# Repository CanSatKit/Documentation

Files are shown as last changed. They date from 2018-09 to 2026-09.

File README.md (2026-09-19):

# CanSat Kit — Documentation

Documentation, user manuals and hardware design files for the **CanSat Kit** —
a starter kit for building a CanSat minisatellite and its ground station,
compatible with the requirements of the *CanSats in Europe* competition and the
Polish CanSat competition organised by ESERO-PL.

This repository holds the released documentation for both generations of the kit.

## Repository contents

| Path | Description |
| --- | --- |
| [`CanSatKit v2/`](CanSatKit%20v2) | Documentation for CanSat Kit rev. 2 (current) |
| [`CanSatKit v1/`](CanSatKit%20v1) | Documentation for CanSat Kit rev. 1.x (legacy) |

Each version folder contains:

- **User manual** — kit contents, technical parameters, connector and
  LED maps, power supply, sensors, radio link, Arduino IDE setup, safety and
  correct-use rules.
- **PCB main** — schematic and PCB drawings (PDF) plus 3D models (STEP, full and
  simplified) of the main CanSat / ground-station board.
- **PCB proto** — schematic, PCB drawings and 3D models of the
  prototyping board.

## Using the 3D models

The `.step` files are provided for mechanical integration of the boards into a
CanSat structure. Where both a full and a simplified model exist, prefer the
simplified one for assembly and envelope checks — it is significantly lighter to
load in CAD software.

## Safety

Before using the kit, read the user manual for your kit revision, in particular
the chapter on safety and correct use. Pay attention to the battery handling and radio transmission
rules described there.

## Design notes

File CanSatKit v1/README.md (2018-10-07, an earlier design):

# Documentation
Documentation, manuals and help for CanSat Kit

# Schematics and Board design files

Available from CircuitMaker:
 - Kit: https://circuitmaker.com/Projects/Details/Michal-Gumiela/CansatKit-ATSAM
 - Protoboard: https://circuitmaker.com/Projects/Details/Michal-Gumiela/CansatKit-Protoboard

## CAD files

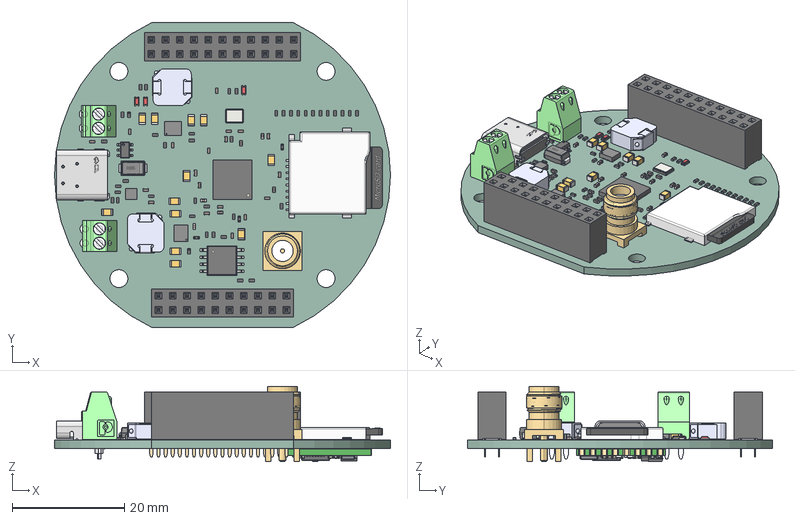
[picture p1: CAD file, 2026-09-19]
CanSatKit v2/PCB main/CansatKit v2.0 - simplified.step
60.0 x 54.4 x 13.5 mm
C_0402_1005Metric x 25
R_0402_1005Metric x 44
CAPC0805 v2 x 12
PinSocket_2x11_P2.54mm_Vertical
SPM6530T-100M x 2
mpt_0.5-2-2.54 x 2
QFN-56-1EP_7x7mm_Pitch0.4mm
SOIC-8_5.3x5.3mm_P1.27mm
User Library-SMA_Stehend_Amp 132134RP-1_1
User Library-SMA_Stehend_Amp 132134RP-1_2
User Library-micro-sd-card
Crystal_SMD_3225-4Pin_3.2x2.5mm
User Library-SOT23-6-2
RNR11 x 2
User Library-led_0603 x 3
VQFN-10_L2.0-W2.0-P0.45-TL
PinSocket_2x10_P2.54mm_Vertical
User Library-RFM96W_Board
User Library-RFM96W_Cap0402 x 21
User Library-RFM96W_SW3dPS-inductor_0402_white x 5
User Library-RFM96W_SW3dPS-SOT-23-6
User Library-RFM96W_QFN28
User Library-RFM96W_TXC_7M
User Library-RFM96W_Res0402 x 4
User Library-RFM96W_User_Library-3-lead_sot23-3
User Library-RFM96W_Goldcontact x 16
CansatKit - RPi-unsaved-export-nT6Vkn_PCB

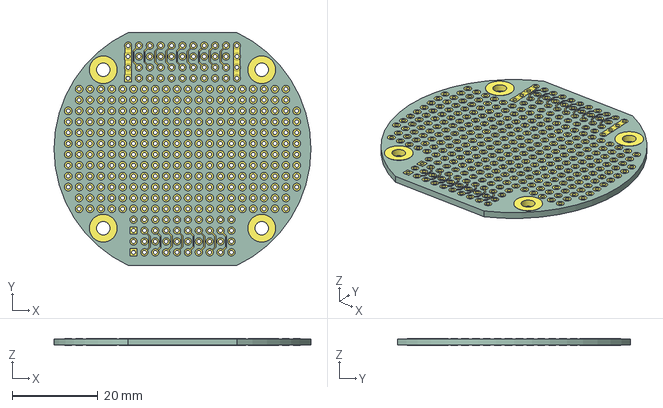
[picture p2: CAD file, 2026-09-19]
CanSatKit v2/PCB proto/CansatKit v2.0 - protoboard.step
60.0 x 54.4 x 1.59 mm
CansatKit - protoboard-unsaved-export-QVb27Q_copper
CansatKit - protoboard-unsaved-export-QVb27Q_PCB

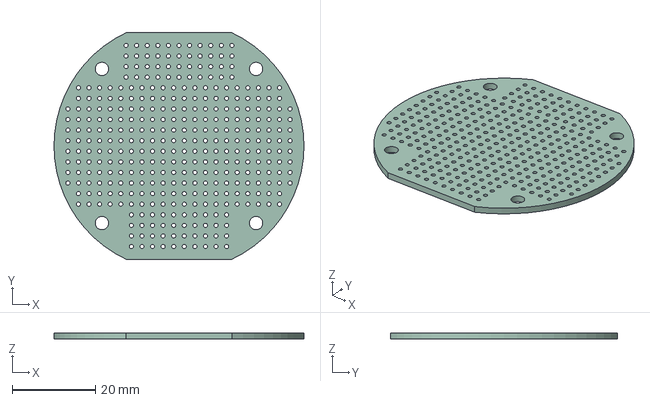
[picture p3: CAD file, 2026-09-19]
CanSatKit v2/PCB proto/CansatKit v2.0 - protoboard simplified.step
60.0 x 54.4 x 1.51 mm

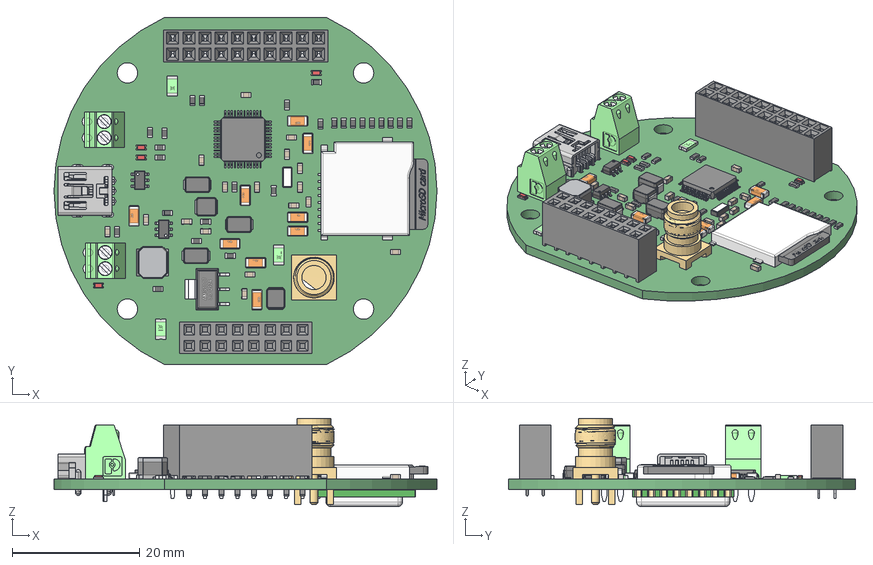
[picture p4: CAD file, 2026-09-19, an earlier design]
CanSatKit v1/PCB Main/main-full.step
60.0 x 54.4 x 13.8 mm
Board
User_Library-micro-sd-card
User_Library-RFM96W_Board
User_Library-RFM96W_Goldcontact x 16
User_Library-res0603-1 x 26
SSW-108-01-X-D_RGB5263440
User_Library-SMD_CAPACITOR x 17
User_Library-nona_SMD075F x 3
User_Library-SMA_Stehend_Amp_132134RP-1_1
User_Library-SMA_Stehend_Amp_132134RP-1_2
User_Library-led_0603LED0603_red x 4
mpt_0.5-2-2 x 2
AMS1117
M20-78310_MOULD
M20-782_CONTACT x 20
SW3dPS-1206_SMD_Capacitor x 9
DO-214AC x 3
User_Library-TQFP-48_pins_TQFP_pin_TQFP_022x07_1 x 48
User_Library-TQFP-48_body_10x1_TQFP_7x7_1
SRN5040series
User_Library-SOT23-6-2 x 2
FX135
AVX-B x 2

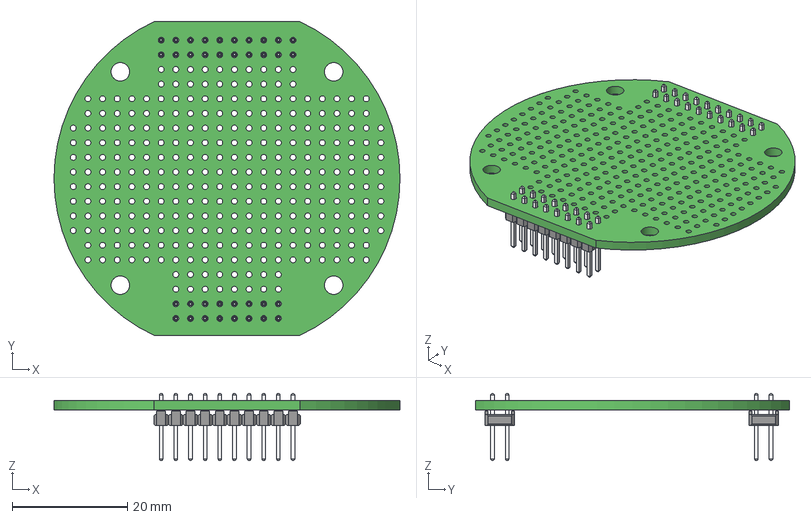
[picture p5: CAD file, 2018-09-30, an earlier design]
CanSatKit v1/PCB Proto/proto.step
60.0 x 54.4 x 11.7 mm
Board
M20-998-MOULD x 2
M20-998-PIN x 36

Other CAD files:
CanSatKit v1/PCB Main/main-simple.step

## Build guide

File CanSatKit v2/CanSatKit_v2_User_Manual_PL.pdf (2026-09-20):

# Dokumentacja zestawu startowego CanSat Kit v2

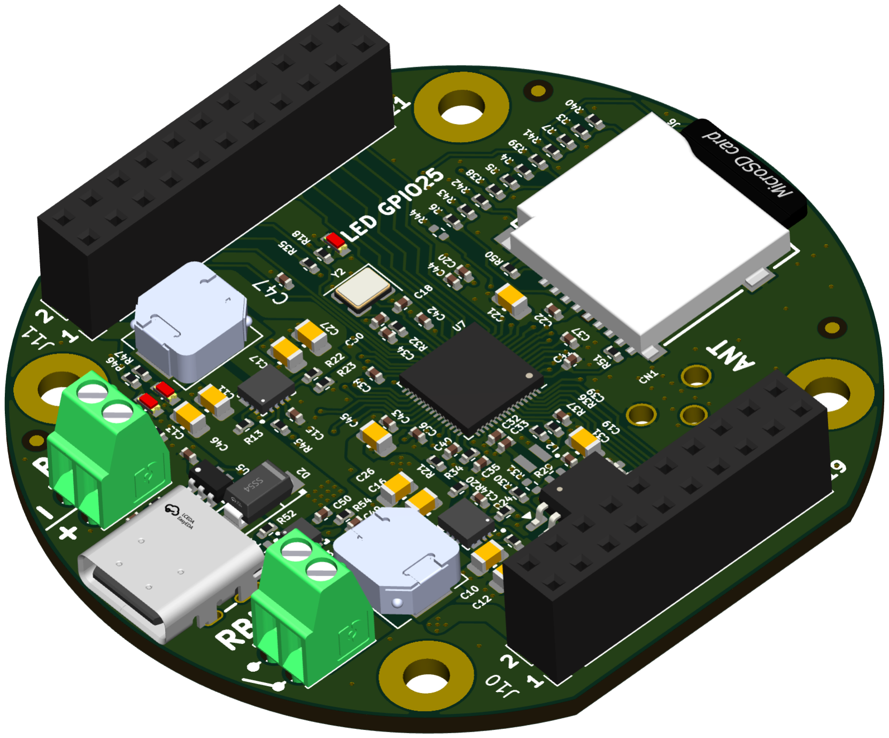
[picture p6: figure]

Rewizja dokumentu: v1.0 (2026-09) Dotyczy zestawu CanSat Kit rev. 2

# 1 Spis treści

## 2 Przeznaczenie zestawu

Zestaw startowy CanSat Kitzaprojektowany został jako platforma do budowy minisatelity CanSat oraz stacji naziemnej zgodnych z wymaganiami konkursu „CanSats in Europe” oraz polskich zawodów CanSat organizowanych przez ESERO-PL.
!"# Przed użyciem zestawu należy zapoznać się z niniejszym dokumentem,

w szczególności z rozdziałem 7. Bezpieczeństwo i zasady prawidłowego użytkowania.

## 3 Elementy zestawu

Zestaw zawiera niezbędne komponenty elektroniczne do wypełnienia misji podstawowej minisatelity CanSat: moduł zasilania (bez akumulatora/baterii), komputer pokładowy, moduły łączności bezprzewodowej, a także czujniki temperatury i ciśnienia atmosferycznego.
Obudowa minisatelity CanSat, system odzysku (np. spadochron) oraz akumulator/bateria zasilająca powinny zostać wykonane/dodane przez użytkownika zestawu według wymagań danego minisatelity.

Zestaw CanSat Kit składa się z następujących elementów:
- 2 x płytka główna CanSata / stacji naziemnej
- 1 x płytka drukowana prototypowa
- 1 x czujnik temperatury - termistor NTC 10k
- 1 x rezystor 10k
- 1 x czujnik ciśnienia BMP280
- 2 x kabel USB-C
- 1 x złącze antenowe SMA
- 1 x listwa kołkowa 2x40-pin 2.54 mm
- 2 x złącze śrubowe typu terminal block 2.54 mm
- 1 x płytka stykowa

- 8 x kabel do płytki stykowej
- 1 x opakowanie ESD

## 4 Parametry techniczne

## 4.1 Płytka główna CanSata / stacji naziemnej

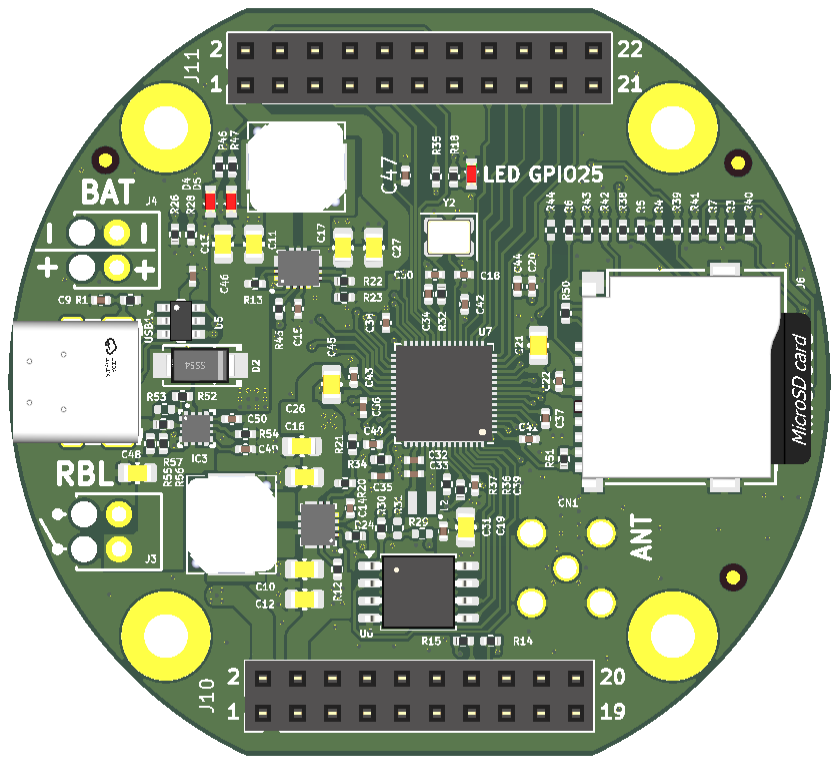
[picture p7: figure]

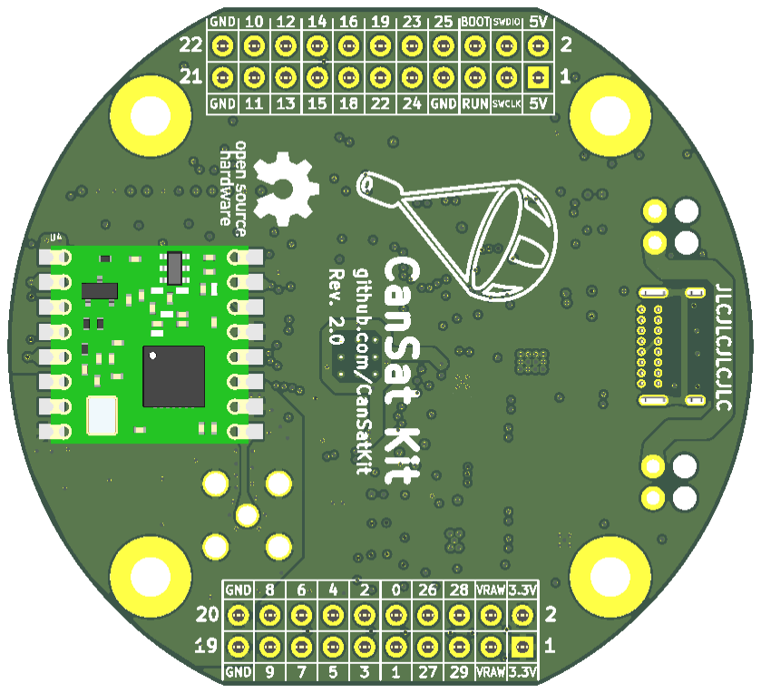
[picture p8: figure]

## 4.1.1 Informacje ogólne

Płytka główna dedykowana jest do użycia zarówno w minisatelicie CanSat, jak i w stacji naziemnej do odbioru danych drogą radiową.
Płytka główna składa się z następujących bloków:
- układ zasilania - umożliwia zasilenie płytki i urządzeń zewnętrznych z ogniw baterii litowo-jonowej (1S, 2S lub 3S), innych ogniw o napięciach w zakresie 3 - 13 V lub złącza USB;
- komputer pokładowy - mikrokontroler zgodny z Arduino / Raspberry Pi Pico 2 (RP2350), z możliwością programowania przez port USB;
- magazyn danych -złącze na kartę microSD, dostępne z poziomu komputera pokładowego;
- moduł łączności bezprzewodowej - układ radiowy nadawczo-odbiorczy, oparty o standard LoRa, z zewnętrznym złączem antenowym.

## 4.1.2 Mapa złącz, gniazd i diod LED

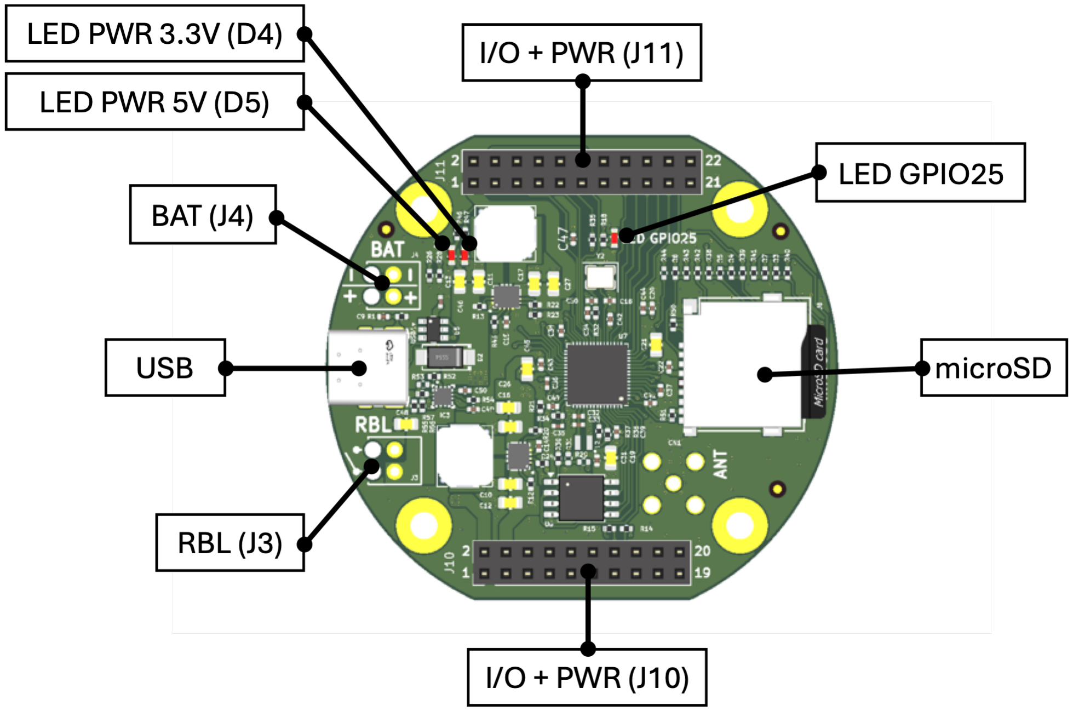
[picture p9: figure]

Tabela 1. Złącza płytki głównej / stacji naziemnej

Nazwa złącza | Opis i funkcje
BAT (J4) | • złącze zasilania zewnętrznego (np. z baterii): 3 - 13 V • raster 2.54 mm • możliwość wlutowania złącza typu listwa kołkowa (header), śrubowego (terminal block) lub przylutowania przewodów (ze stress reliefem) (https://cdn.sparkfun.com/assets/5/3/b/f/2/526d7970757b7f7f708b4568.jpg)
RBL (J3) | • zworka zasilania - raster 2.54 mm • możliwość wpięcia głównego włącznika
USB-C (USB1) | • zasilanie • programowanie mikrokontrolera z Arduino IDE • przesyłanie danych (Serial port) • po więcej szczegółów zobacz dokumentację Arduino/ Raspberry Pi Pico 2 dotyczącą złącza USB
J10, J11 | • złącze kołkowe żeńskie 2.54 mm • dostępne napięcia zasilające • wyprowadzone wejścia/wyjścia mikrokontrolera
micro SD | • złącze na karty pamięci micro SD • podłączone do mikrokontrolera - zob. 4.1.5
ANT | • złącze anteny modułu radiowego • możliwość przylutowania złącza SMA (https://media.rs-online.com/t_large/F6163422-01.jpg) np. do wkręcenia większej anteny (w stacji naziemnej) • możliwość przylutowania anteny ćwierćfalowej wykonanej z przewodu

4.1.2.1 Złącze J11

!"# Standard napięć dla pinów mikrokontrolera to 3.3 V. Podłączenie urządzeń pracujących w innych standardach napięciowych (np. 5 V) może skutkować uszkodzeniem zestawu.

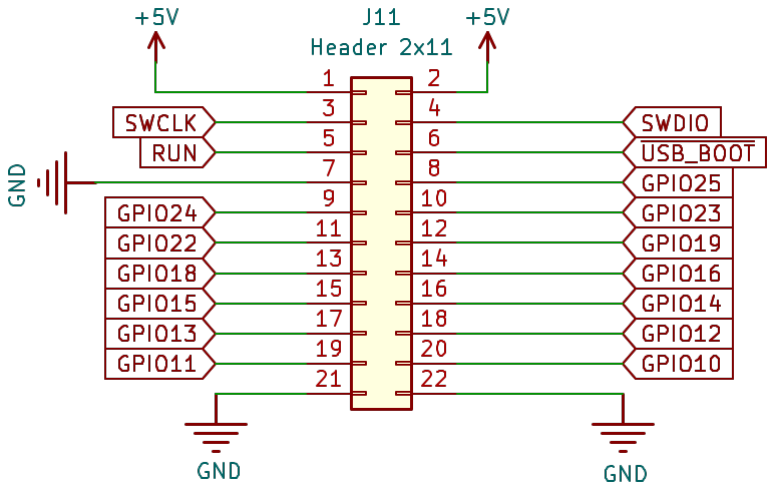
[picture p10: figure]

Tabela 2. Mapa pinów złącza J11

Pin nr | Nazwa na schemacie | Linia RP2350 | Opis | Funkcje alternatywne (RP2350)
1 | 5V | - | Zasilanie +5 V (wyjście przetwornicy IC2) | -
2 | 5V | - | Zasilanie +5 V (wyjście przetwornicy IC2) | -
3 | SWCLK | SWCLK | Zegar interfejsu SWD - programowanie i debugowanie zewnętrznym programatorem | -
4 | SWDIO | SWDIO | Linia danych interfejsu SWD | -
5 | RUN | RUN | Reset mikrokontrolera - zwarcie do GND powoduje reset (linia aktywna w stanie niskim) | -
6 | BOOT | QSPI_SS | Wymuszenie trybu bootloadera USB - zwarcie do GND w chwili włączenia zasilania lub resetu (przez rezystor 1 kΩ) | -
7 | GND | - | Masa | -
8 | 25 | GPIO25 | Wejście/wyjście cyfrowe (GPIO), podłączona zielona dioda LED (D1) - odpowiednik LED_BUILTIN | SPI1 CSn, I2C0 SCL, UART1 RX, PWM
9 | 24 | GPIO24 | Wejście/wyjście cyfrowe (GPIO) | SPI1 RX, I2C0 SDA, UART1 TX, PWM
10 | 23 | GPIO23 | Wejście/wyjście cyfrowe (GPIO) | SPI0 TX, I2C1 SCL, PWM
11 | 22 | GPIO22 | Wejście/wyjście cyfrowe (GPIO). Opcjonalnie sygnał DIO1 modułu radiowego - zob. przypis 1 | SPI0 SCK, I2C1 SDA, PWM
12 | 19 | GPIO19 | Interfejs SPI0 - linia MOSI (TX). Podłączony czytnik kart microSD oraz moduł radiowy | SPI0 TX, I2C1 SCL, PWM
13 | 18 | GPIO18 | Interfejs SPI0 - linia SCK. Podłączony czytnik kart microSD oraz moduł radiowy | SPI0 SCK, I2C1 SDA, PWM
14 | 16 | GPIO16 | Interfejs SPI0 - linia MISO (RX). Podłączony czytnik kart microSD oraz moduł radiowy | SPI0 RX, I2C0 SDA, UART0 TX, PWM
15 | 15 | GPIO15 | Wejście/wyjście cyfrowe (GPIO) | SPI1 TX, I2C1 SCL, UART0 RX, PWM
16 | 14 | GPIO14 | Wejście/wyjście cyfrowe (GPIO) | SPI1 SCK, I2C1 SDA, UART0 TX, PWM
17 | 13 | GPIO13 | Wejście/wyjście cyfrowe (GPIO) | SPI1 CSn, I2C0 SCL, UART0 RX, PWM
18 | 12 | GPIO12 | Wejście/wyjście cyfrowe (GPIO) | SPI1 RX, I2C0 SDA, UART0 TX, PWM
19 | 11 | GPIO11 | Wejście/wyjście cyfrowe (GPIO) | SPI1 TX, I2C1 SCL, PWM
20 | 10 | GPIO10 | Wejście/wyjście cyfrowe (GPIO) | SPI1 SCK, I2C1 SDA, PWM
21 | GND | - | Masa | -

22 | GND | - | Masa | -

4.1.2.2 Złącze J10

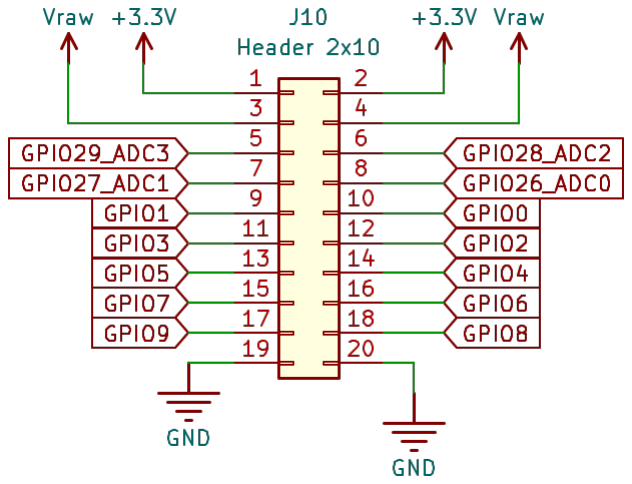
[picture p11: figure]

Tabela 3. Mapa pinów złącza J10

Pin nr | Nazwa na schemacie | Linia RP2350 | Opis | Funkcje alternatywne (RP2350)
1 | 3.3V | - | Zasilanie +3.3 V (wyjście przetwornicy IC1) | -
2 | 3.3V | - | Zasilanie +3.3 V (wyjście przetwornicy IC1) | -
3 | VRAW | - | Napięcie wejściowe za zabezpieczeniem (eFuse) | -
4 | VRAW | - | Napięcie wejściowe za zabezpieczeniem (eFuse) | -
5 | 29 | GPIO29 | Wejście/wyjście cyfrowe (GPIO), wejście analogowe ADC3 | ADC3, SPI1 CSn, UART0 RX, I2C0 SCL, PWM
6 | 28 | GPIO28 | Wejście/wyjście cyfrowe (GPIO), wejście analogowe ADC2 | ADC2, SPI1 RX, UART0 TX, I2C0 SDA, PWM
7 | 27 | GPIO27 | Wejście/wyjście cyfrowe (GPIO), wejście analogowe ADC1 | ADC1, SPI1 TX, I2C1 SCL, PWM
8 | 26 | GPIO26 | Wejście/wyjście cyfrowe (GPIO), wejście analogowe ADC0 | ADC0, SPI1 SCK, I2C1 SDA, PWM
9 | 1 | GPIO1 | Wejście/wyjście cyfrowe (GPIO), domyślnie UART0 RX (w Arduino IDE Serial1) | UART0 RX, SPI0 CSn, I2C0 SCL, PWM
10 | 0 | GPIO0 | Wejście/wyjście cyfrowe (GPIO), domyślnie UART0 TX (w Arduino IDE Serial1) | UART0 TX, SPI0 RX, I2C0 SDA, PWM
11 | 3 | GPIO3 | Wejście/wyjście cyfrowe (GPIO) | SPI0 TX, I2C1 SCL, UART0 RX, PWM
12 | 2 | GPIO2 | Wejście/wyjście cyfrowe (GPIO) | SPI0 SCK, I2C1 SDA, UART0 TX, PWM
13 | 5 | GPIO5 | Interfejs I2C - linia SCL (clock). Na płytce rezystor podciągający 4.7 kΩ do 3.3 V | I2C0 SCL, SPI0 CSn, UART1 RX, PWM
14 | 4 | GPIO4 | Interfejs I2C - linia SDA (data). Na płytce rezystor podciągający 4.7 kΩ do 3.3 V | I2C0 SDA, SPI0 RX, UART1 TX, PWM
15 | 7 | GPIO7 | Wejście/wyjście cyfrowe (GPIO) | I2C1 SCL, SPI0 TX, PWM
16 | 6 | GPIO6 | Wejście/wyjście cyfrowe (GPIO) | I2C1 SDA, SPI0 SCK, PWM
17 | 9 | GPIO9 | Wejście/wyjście cyfrowe (GPIO) | SPI1 CSn, I2C0 SCL, UART1 RX, PWM
18 | 8 | GPIO8 | Wejście/wyjście cyfrowe (GPIO) | SPI1 RX, I2C0 SDA, UART1 TX, PWM
19 | GND | - | Masa | -
20 | GND | - | Masa | -

4.1.2.3 Diody

Tabela 4. Diody świecące (LED) dostępne na płytce i ich funkcje

Nazwa diody | Opis
LED GPIO25 | Dioda LED podłączona do pinu GPIO25 mikrokontrolera - użyj np. przykładu „Blink” z Arduino, kompatybilna z diodą w Raspberry Pi Pico 2 i Arduino (LED_BUILTIN)
LED PWR D4 | Dioda sygnalizująca obecność napięcia na linii zasilania 3.3 V
LED PWR D5 | Dioda sygnalizująca obecność napięcia na linii zasilania 5 V

## 4.1.3Układ zasilania

Układ zasilania obecny na płytce odpowiada za konwersję energii elektrycznej, dystrybucję na płytce głównej do zasilania jej podzespołów oraz dostarczenie energii do zasilenia układów dołączanych do płytki głównej przez użytkownika.

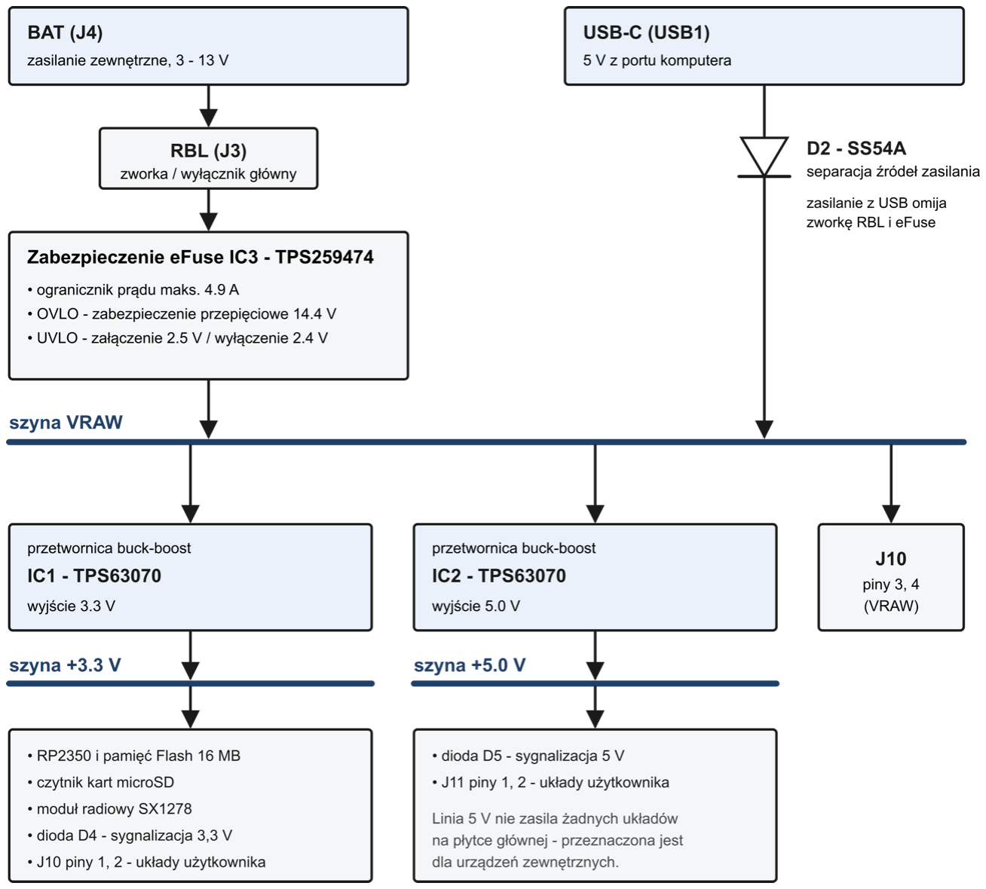
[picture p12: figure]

Płytka główna może być zasilana na kilka różnych sposobów, które zostały przedstawione poniżej:

1) Złącze zasilające J4 (BAT)
̶ minimalne napięcie wejściowe: 3.0 V
̶ maksymalne napięcie wejściowe: 13.0 V
̶ zasilenie układów płytki ze złącza BAT następuje tylko wtedy, gdy zwarta jest zworka oznaczona jako RBL,
̶ zalecane jest zasilanie płytki z akumulatorów litowo-jonowych od 1 do 3 celi szeregowo (1S
- 3S)
̶ Przy zasilaniu ze złącza BAT (J4) napięcie Vraw będzie odpowiadało dostarczonemu napięciu na tym złączu

2) Złącze USB-C (USB1)
̶ maksymalne napięcie wejściowe: 5.5 V
̶ podłączenie płytki za pomocą złącza USB-C spowoduje zasilenie jej modułów (w tym pojawienie się napięcia na liniach zasilających 5 V i 3.3 V na złączu J10 i J11) niezależnie od stanu zworki RBL.
̶ Przy podłączeniu złącza USB napięcie Vraw będzie wynosiło ok. 4.5-5 V (podłączenie przez diodę Schottkiego)

!"# Zamiana polaryzacji zasilania może powodować nieodwracalne uszkodzenia na płytce!

!"# Podłączenie napięcia większego niż maksymalne napięcie podane w specyfikacji dla danego wejścia może spowodować nieodwracalne uszkodzenia na płytce!

Układ dostarcza następujące linie zasilania na złączach J10 i J11:
- linia 5 V
- napięcie nominalne: 5.0 V
- wydajność prądowa:
- 1 A - dla napięcia wejściowego min. 3 V (1S/1xli-ion)
- 1.5 A - dla napięcia wejściowego min. 6 V (2S/2xli-ion)
- linia 3.3 V
- napięcie nominalne: 3.3 V
- wydajność prądowa:
- 1 A - dla napięcia wejściowego min. 3 V (1S/1xli-ion)
- 1.5 A - dla napięcia wejściowego min. 6 V (2S/2xli-ion)
- linia Vraw
- bezpośrednie napięcie z baterii (za zworką RBL) lub złącza USB-C (przez diodę Schottkiego)
- wydajność prądowa: zabezpieczenie na maksymalnie 4.9 A

!"# W przypadku poboru większego prądu niż podano w specyfikacji dla danej linii, zostanie aktywowane zabezpieczenie nadprądowe, które skutkuje odłączeniem linii na pewien okres czasu. Cała płytka powinna zostać odłączona od zasilania na kilka minut, aby przywrócić napięcie na odłączonej linii.

Zworka RBL:
Zworka RBL jest podłączona szeregowo z pinem „+” złącza BAT (J4). Zalecane jest podłączenie przełącznika do złącza RBL (J3), który będzie pełnił funkcję głównego włącznika CanSata. Jeśli przełącznik jest zlokalizowany w innym miejscu, złącze RBL (J3) można zewrzeć.

!"# Zworka ma wpływ tylko i wyłącznie na odłączanie/włączanie źródła zasilania podpiętego do złącza BAT (J4). Nie ma ona wpływu, jeśli płytka zasilana jest przez złącze USB-C (USB1).

## 4.1.4 Mikrokontroler

Raspberry Pi RP2350A to wydajny, dwurdzeniowy mikrokontroler o architekturze hybrydowej: zawiera dwa rdzenie ARM Cortex-M33 oraz dwa rdzenie Hazard3 (RISC-V), z których użytkownik wybiera parę uruchamianą po starcie. Płytka jest programowo zgodna z modułem Raspberry Pi Pico 2.
Programowanie mikrokontrolera odbywa się przez port USB-C bezpośrednio z Arduino IDE (środowisko samo przełącza płytkę w tryb bootloadera).
Parametry techniczne
Mikrokontroler | RP2350A, QFN-60 7 x 7 mm
Architektura rdzeni | 2 x ARM Cortex-M33 (z FPU i DSP) lub 2 x Hazard3 (RISC-V RV32IMAC)
Napięcie pracy wejść/wyjść | 3.3 V
Pamięć Flash | 16 MB (zewnętrzna, W25Q128JVS, magistrala QSPI)
Pamięć SRAM | 520 KB
Częstotliwość zegara | 150 MHz
Rezonator | kwarc 12 MHz (Y2)

Przetwornik ADC | 12-bitowy, 4 kanały (GPIO26 - GPIO29)
USB | natywny kontroler USB 1.1 (Full Speed, 12 Mb/s), tryb device

Dostępne dla użytkownika interfejsy zostały wymienione w tabelach 4.1.2.1 oraz 4.1.2.2.

!"# Wydajność prądowa pojedynczego pinu mikrokontrolera jest konfigurowalna (2, 4, 8 lub 12 mA). Wartość domyślna to 4 mA. Zaleca się nieprzekraczanie 8 mA na pin.

## 4.1.5 Czytnik kart microSD

Czytnik kart microSD został podłączony do mikrokontrolera poprzez interfejs SPI, zgodnie z poniższą tabelą.
Pin karty SD (funkcja w trybie SPI karty SD) | Pin mikrokontrolera
DAT0 (MISO) | GPIO16
CMD (MOSI) | GPIO19
CLK (Clock / SCK) | GPIO18
DAT3 (Chip Select / CS) | GPIO21

🛈 Więcej informacji o podłączaniu karty SD do Arduino można znaleźć

w dokumentacji biblioteki (https://www.arduino.cc/en/Reference/SD) oraz poradniku. (https://www.arduino.cc/en/Reference/SDCardNotes)

## 4.1.6 Moduł radiowy

Moduł radiowy SX1278 został podłączony do mikrokontrolera poprzez interfejs SPI oraz dodatkowe piny GPIO, zgodnie z poniższą tabelą:

Pin modułu SX1278 | Pin mikrokontrolera
MISO | GPIO16
MOSI | GPIO19

SCK | GPIO18
NSS (Chip Select) | GPIO17
DIO0 | GPIO20
DIO1 | GPIO22 (przypis 1)
RESET | niepodłączony

Przypisy:

1
- domyślnie pin DIO1 nie jest podłączony do pinu GPIO22 mikrokontrolera; aby to zrobić, należy wlutować rezystor R44 - rozmiar SMD 0402 o wartości ok. 100 Ω lub zworkę, np. kawałek drutu. Nie jest to jednak konieczne do wykonania misji CanSata.

🛈 Szczegółowe informacje o module radiowym SX1278 można znaleźć w jego

dokumentacji. (https://cdn-shop.adafruit.com/product-files/3179/sx1276_77_78_79.pdf)

## 4.1.7 Parametry mechaniczne

Kształt płytki: koło o promieniu 30 mm ze ściętymi fragmentami - w miejscu ścięcia szerokość 54.4 mm.
Na płytce rozmieszczone są 4 otwory montażowe przeznaczone na śruby M3 (średnica 3.2 mm). Otwory posiadają metalizowane obręcze (średnica 6.5 mm), podłączone bezpośrednio do masy (GND). Dostępne są modele 3D w formacie STEP.

## 4.2 Czujnik temperatury

Termistor NTC (ang. Negative Temperature Coefficient) to rezystor, którego rezystancja maleje wraz ze wzrostem temperatury. W odróżnieniu od czujników aktywnych termistor nie wytwarza napięcia proporcjonalnego do temperatury - jest elementem czysto biernym, dlatego do pomiaru konieczny jest dzielnik napięcia i przetwornik analogowo-cyfrowy mikrokontrolera.

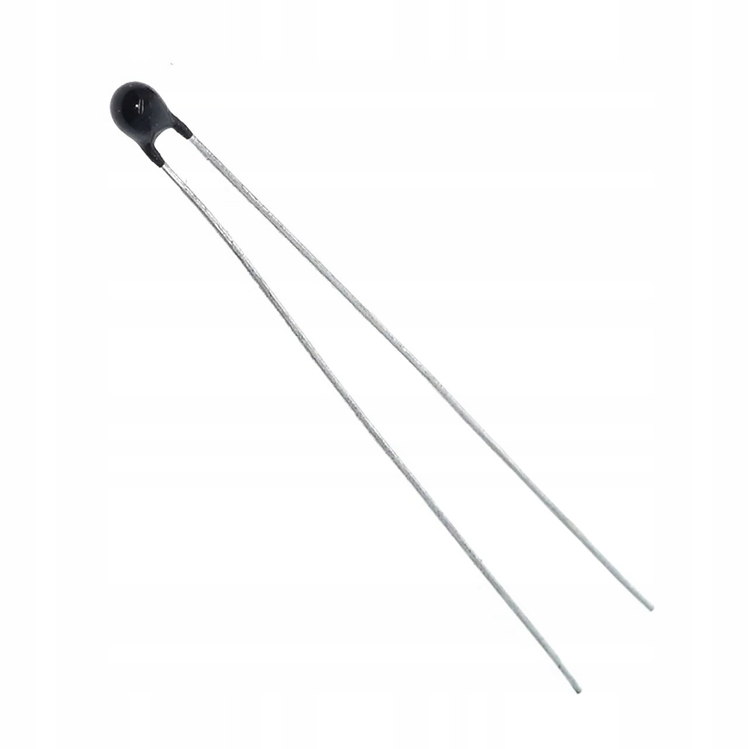
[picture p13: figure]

Zależność rezystancji od temperatury opisuje w przybliżeniu równanie Beta:

1/T = 1/T25 + (1/B) * ln(R / R25)

gdzie T i T25 wyrażone są w kelwinach (T25 = 298.15 K, czyli 25 °C), R25 to rezystancja termistora w temperaturze 25 °C, a B to współczynnik materiałowy podawany w dokumentacji czujnika.
- rezystancja nominalna R25: 10 kΩ
- współczynnik B (B25/85): typowe wartości dla termistorów 10 kΩ mieszczą się w zakresie 3435
- 3988
Termistor pracuje w dzielniku napięcia zasilanym z linii 3.3 V płytki głównej. Rezystor odniesienia R1 o wartości 10 kΩ łączy linię 3.3 V z węzłem pomiarowym (V_ADC), natomiast termistor łączy węzeł pomiarowy (V_ADC) z masą. Węzeł pomiarowy podłączony jest do wejścia przetwornika analogowo-cyfrowego mikrokontrolera (np. pin GPIO27). Polecane jest również dodanie kondensatora (oznaczenie C1) w celu poprawy jakości pomiarów.

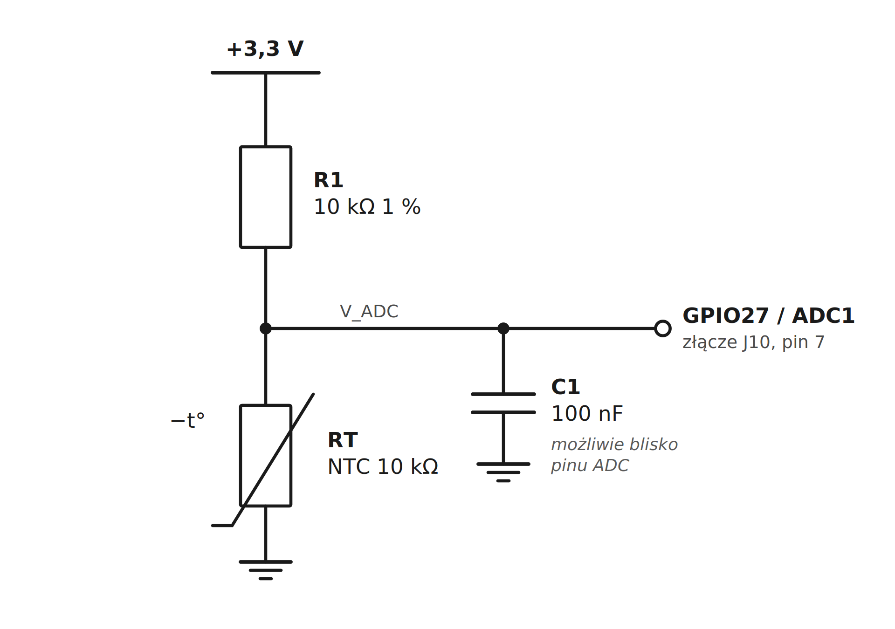
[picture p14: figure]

Charakterystyka dzielnika pomiarowego z termistorem NTC 10 kΩ:

Temperatura | Rezystancja NTC | Napięcie na ADC | Wynik ADC | Rozdzielczość
−40 °C | 401.9 kΩ | 3.220 V | 3996 | 7 LSB/°C
−20 °C | 105.4 kΩ | 3.014 V | 3740 | 20 LSB/°C
−10 °C | 58.3 kΩ | 2.816 V | 3495 | 29 LSB/°C
0 °C | 33.6 kΩ | 2.543 V | 3156 | 38 LSB/°C
+10 °C | 20.2 kΩ | 2.206 V | 2738 | 45 LSB/°C
+25 °C | 10.0 kΩ | 1.650 V | 2048 | 46 LSB/°C
+40 °C | 5.30 kΩ | 1.143 V | 1419 | 37 LSB/°C
+50 °C | 3.59 kΩ | 0.871 V | 1081 | 30 LSB/°C
+60 °C | 2.49 kΩ | 0.657 V | 815 | 23 LSB/°C
+85 °C | 1.09 kΩ | 0.323 V | 401 | 11 LSB/°C

Uwaga - pinu wejścia analogowego, do którego podłączony jest dzielnik, nie wolno konfigurować jako wejścia cyfrowego (wywołanie pinMode(pin_analogowy, INPUT) w programie). GPIO z włączonym buforem wejściowym, którego napięcie znajduje się pomiędzy poziomami logicznymi
- a tak jest zawsze w dzielniku pomiarowym - może pobierać prąd do 120 µA, co całkowicie zaburza pomiar. Funkcja analogRead() wyłącza bufor wejściowy samodzielnie, ale robi to tylko przy pierwszym użyciu danego pinu; późniejsze wywołanie pinMode() na tym samym pinie ponownie włączy bufor i nie zostanie cofnięte.

## 4.3 Czujnik ciśnienia atmosferycznego

🛈 Szczegółowe informacje o czujniku ciśnienia atmosferycznego BMP280 można

znaleźć w jego dokumentacji. (http://www.ti.com/lit/ds/symlink/lm35.pdf)

## 4.3.1 Parametry pomiarowe

- Zakres pomiaru ciśnienia: 300 - 1100 hPa
- Zakres pomiaru temperatury: -40 - 85 °C
- Dokładność bezwzględna (0 - 65 °C): ±1 hPa
- Dokładność względna (700 - 900 hPa przy +25 °C do +40 °C): ±0.12 hPa (odpowiada ±1 m)
- Czas pomiaru: od 5.5 ms

## 4.3.2 Zasilanie

- zakres napięcia zasilania: 1.71 V - 3.6 V
- pobór prądu: < 1 mA

## 4.3.3 Interfejs

- komunikacja z mikrokontrolerem poprzez cyfrowy interfejs I2C (linie SDA i SCL)
- adres I2C czujnika: 0x76
- zarówno płytka główna CanSat Kit, jak i czujnik na swojej płytce posiadają odpowiednie rezystory podciągające linie SDA i SCL (pull-up), wymagane do prawidłowej pracy interfejsu I2C
- alternatywnie możliwość użycia interfejsu SPI - szczegóły dostępne w dokumentacji czujnika

## 4.3.4 Pinout

Pogrubione skróty obecne są na spodniej stronie płytki czujnika:

- VCC - Napięcie zasilania 3.3 V
- GND - Masa
- SCL - Zegar I2C / SPI
- SDA - Linia danych I2C / MOSI w trybie SPI
- CSB - Chip Select (standardowo nieużywany, nieprzylutowany)
- SD0 - MISO w trybie SPI (standardowo nieużywany, nieprzylutowany)

## 4.3.5 Parametry mechaniczne

- Czujnik jest przylutowany do niewielkiej płytki PCB ze złączem w postaci listwy kołkowej 6-pin o rastrze 2.54 mm.
- Dostępne są również dwa otwory montażowe o średnicy 3 mm.
- Rozmiar płytki: 15 x 10 mm
- Masa: 0.6 g

## 5 Uruchomienie zestawu

## 5.1 Instalacja i konfiguracja środowiska Arduino IDE

1) Pobierz program Arduino IDE ze strony https://www.arduino.cc/en/main/software dla swojego systemu operacyjnego.
2) Zainstaluj oprogramowanie zgodnie z instrukcjami dla swojego systemu operacyjnego: https://docs.arduino.cc/software/ide-v2/tutorials/getting-started/ide-v2-downloading-and-installing/
3) Uruchom Arduino IDE i przejdź do opcji: „File → Preferences”. W polu „Additional boards manager URLs” dodaj adres rdzenia arduino-pico:

https://github.com/earlephilhower/arduino-pico/releases/download/global/package_rp2040_index.json

4) Przejdź do „Tools → Board → Boards Manager…”, wyszukaj „pico” i zainstaluj paczkę „Raspberry Pi Pico/RP2040/RP2350” w najnowszej wersji.

5) Po zainstalowaniu pakietu wybierz rodzaj płytki: „Tools → Board → Raspberry Pi RP2040/RP2350 → Generic RP2350”.
6) Ustaw rozmiar pamięci w menu: „Tools → Flash Size to 16MB (no FS)”
7) Przejdź do zakładki „Sketch → Include Library → Add .ZIP Library…” i wybierz plik „.zip” z biblioteką dostarczony z zestawem CanSat Kit lub pobierz aktualną wersję ze strony https://github.com/CanSatKit/CanSatKit-v2-library lub wyszukaj bibliotekę do zainstalowania w Arduino IDE („CanSatKit-v2-library”)
8) W menu „File → Examples → CanSat Kit v2 library” dostępne są przykładowe programy.

## 5.2 Podłączanie płytki do komputera za pomocą portu USB

1) Używając kabla USB-C dołączonego do zestawu podłącz jedną z płytek głównych CanSat Kit do komputera PC.
2) W menu „Tools à Port” powinna być widoczna płytka Arduino pod nazwą „COMx (Generic RP2350, Raspberry Pi Pico2)”. Po wybraniu tego portu możliwe będzie programowanie i komunikacja z podłączoną płytką.

## 5.3 Wgranie pierwszego programu „Hello CanSat”

1) Otwórz przykładowy program „File à Examples à CanSat Kit v2 library à HelloCanSatKit”
2) Upewnij się, że płytka jest podłączona do komputera, a Arduino IDE ustawione jest zgodnie z punktami 5.1 oraz 5.2.
3) Po wciśnięciu przycisku „Upload” (na pierwszym rysunku poniżej) rozpocznie się kompilacja i wgrywanie oprogramowania na płytkę (drugi rysunek):
4) Po zakończeniu wgrywania nowy program jest wykonywany przez płytkę CanSat Kit.

5) Ostatnim krokiem jest weryfikacja działania programu.
̶ Dioda LED GPIO25 powinna migać co 1 sekundę.
̶ Po otwarciu Monitora Portu Szeregowego (Serial Monitor): „Tools à Serial Monitor” lub ikona lupy w prawym, górnym rogu Arduino IDE na ekranie powinny wyświetlać się komunikaty przesyłane do komputera przez płytkę CanSat Kit.
Wynik działania programu jest widoczny na obrazku poniżej:

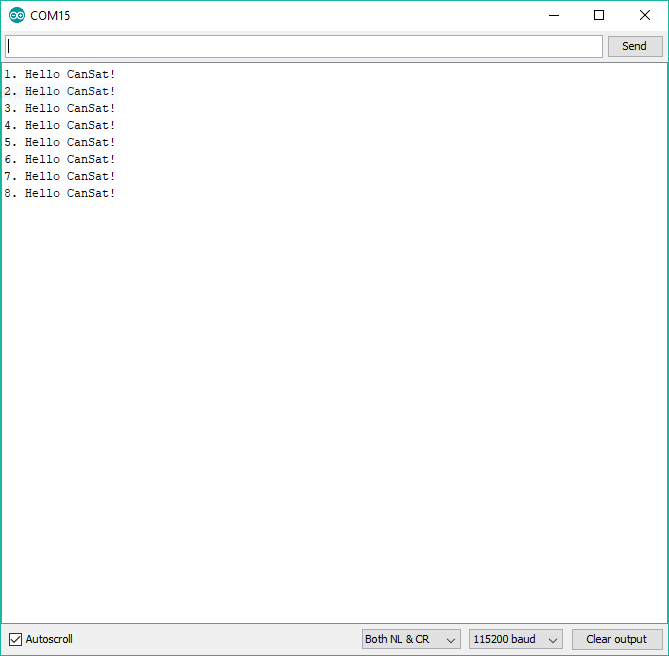
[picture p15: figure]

## 5.4 Podłączenie i testy czujnika temperatury

1) Podłącz czujnik temperatury do płytki CanSat Kit zgodnie ze schematem z rozdziału instrukcji poświęconego czujnikowi temperatury.
2) Otwórz przykładowy program „File à Examples à CanSat Kit v2 library à TemperatureSensor” i wgraj go na płytkę.

3) Po otwarciu Monitora Portu Szeregowego (Serial Monitor) na ekranie wyświetlone zostaną pomiary temperatury. Alternatywnie można otworzyć aplikację „Kreślarka”: „Tools à Serial Plotter” (lub kombinacja klawiszy Ctrl-Shift-L).

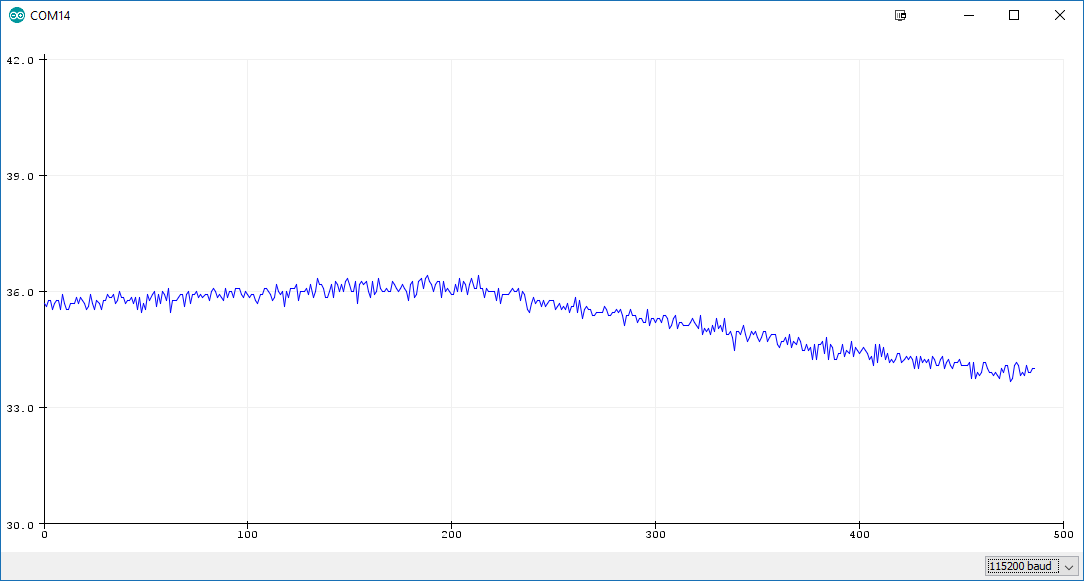
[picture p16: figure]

## 5.5 Podłączenie i testy czujnika ciśnienia

1) Podłącz czujnik ciśnienia do płytki CanSat Kit w następujący sposób:
Piny płytki CanSat Kit | Piny czujnika ciśnienia BMP280
+3.3 V | VCC
GND | GND
SCL (GPIO5) | SCL
SDA (GPIO4) | SDA
2) Otwórz przykładowy program „File à Examples à CanSat Kit v2 library à PressureSensor” i wgraj go na płytkę.
3) Po otwarciu Monitora Portu Szeregowego (Serial Monitor) na ekranie wyświetlone zostaną pomiary ciśnienia. Alternatywnie można otworzyć aplikację „Kreślarka”: „Tools à Serial Plotter” (lub kombinacja klawiszy Ctrl-Shift-L).

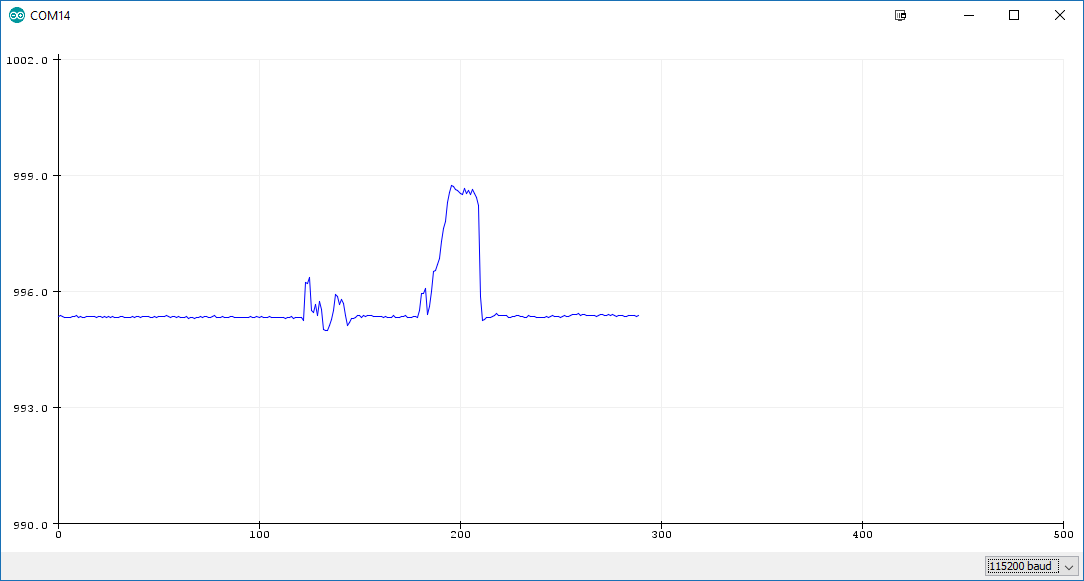
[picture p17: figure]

## 5.6 Używanie karty micro SD

Do uruchomienia tego przykładu konieczne będzie włożenie karty pamięci micro SD do odpowiedniego slotu na płytce. Polecane jest używanie kart o niewielkich rozmiarach np. 128 MB - 8 GB.
1) Włóż kartę micro SD do slotu na płytce (stykami karty SD do płytki), podłącz płytkę kablem USB do komputera.
2) W środowisku Arduino IDE otwórz przykład Datalogger: „File à Examples à SD à Datalogger”.

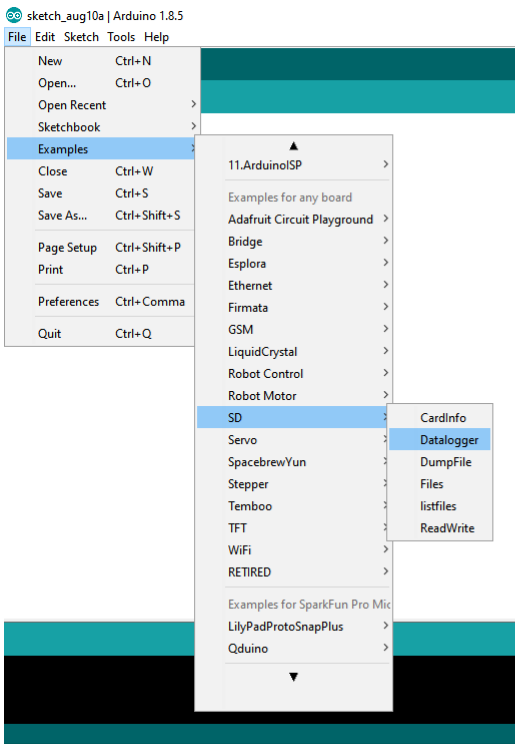
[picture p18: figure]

3) Dokonaj niezbędnych modyfikacji w programie: ̶ const int _MISO = 16;
̶ const int _MOSI = 19;
̶ const int _CS = 21;
̶ const int _SCK = 18;
4) Skompiluj i wgraj program na płytkę.
5) Otwórz monitor portu szeregowego i obserwuj dane które powinny być zapisane na kartę SD (program wyświetla i zapisuje wartości z trzech wejść analogowych do których można podłączyć np. czujnik NTC). W przypadku błędów inicjalizacji karty SD lub błędów zapisu stosowne informacje będą również wyświetlone.
6) Po pewnym czasie (kilku minutach) odłącz płytkę od zasilania, wysuń kartę ze slotu i włóż do czytnika w swoim komputerze PC. Odczytaj zawartość pliku z danymi i sprawdź, czy są one poprawne.

## 5.7 Używanie modułu radiowego

Do tego przykładu potrzebne będą dwie płytki CanSat Kit - jedna będzie pełniła rolę nadajnika (CanSat), a druga odbiornika (stacja naziemna).

## 5.7.1 Konfiguracja nadajnika

1) Otwórz przykładowy program „File à Examples à CanSat Kit v2 library à RadioTransmitHelloCanSat” i wgraj go na płytkę.
2) Otwórz monitor portu szeregowego, zaobserwuj pojawiające się komunikaty - porównaj z poniższymi:

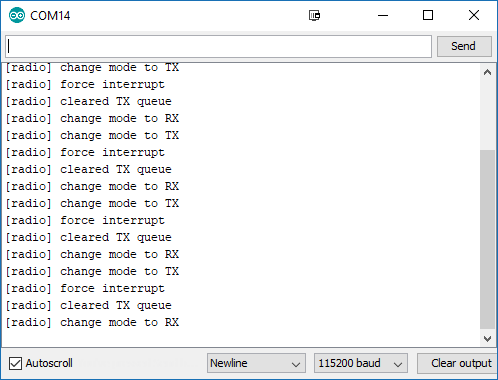
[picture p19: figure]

3) Zaobserwuj miganie diody LED GPIO25 - sygnalizuje to poprawną pracę nadajnika.

## 5.7.2 Konfiguracja odbiornika

Następnie należy uruchomić odbiornik radiowy na drugiej płytce.
1) Podłącz drugą płytkę do komputera.
2) Wybierz port COM odpowiadający drugiej płytce.
3) Otwórz przykładowy program „File à Examples à CanSat Kit v2 library à RadioReceiver” i wgraj go na płytkę.
4) Otwórz monitor portu szeregowego, zaobserwuj pojawiające się komunikaty - oznaczają one odebrane pakiety:

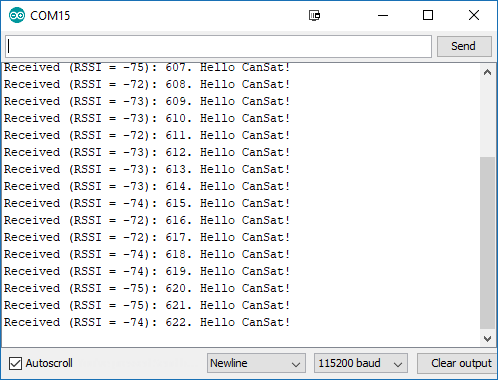
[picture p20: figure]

5) Parametr RSSI (Receiver Signal Strength Indicator) wskazuje siłę sygnału w odbiorniku. Zaobserwuj jak zbliżanie i oddalanie płytek wpływa na wartość RSSI.

## 5.8 Podłączenie anten

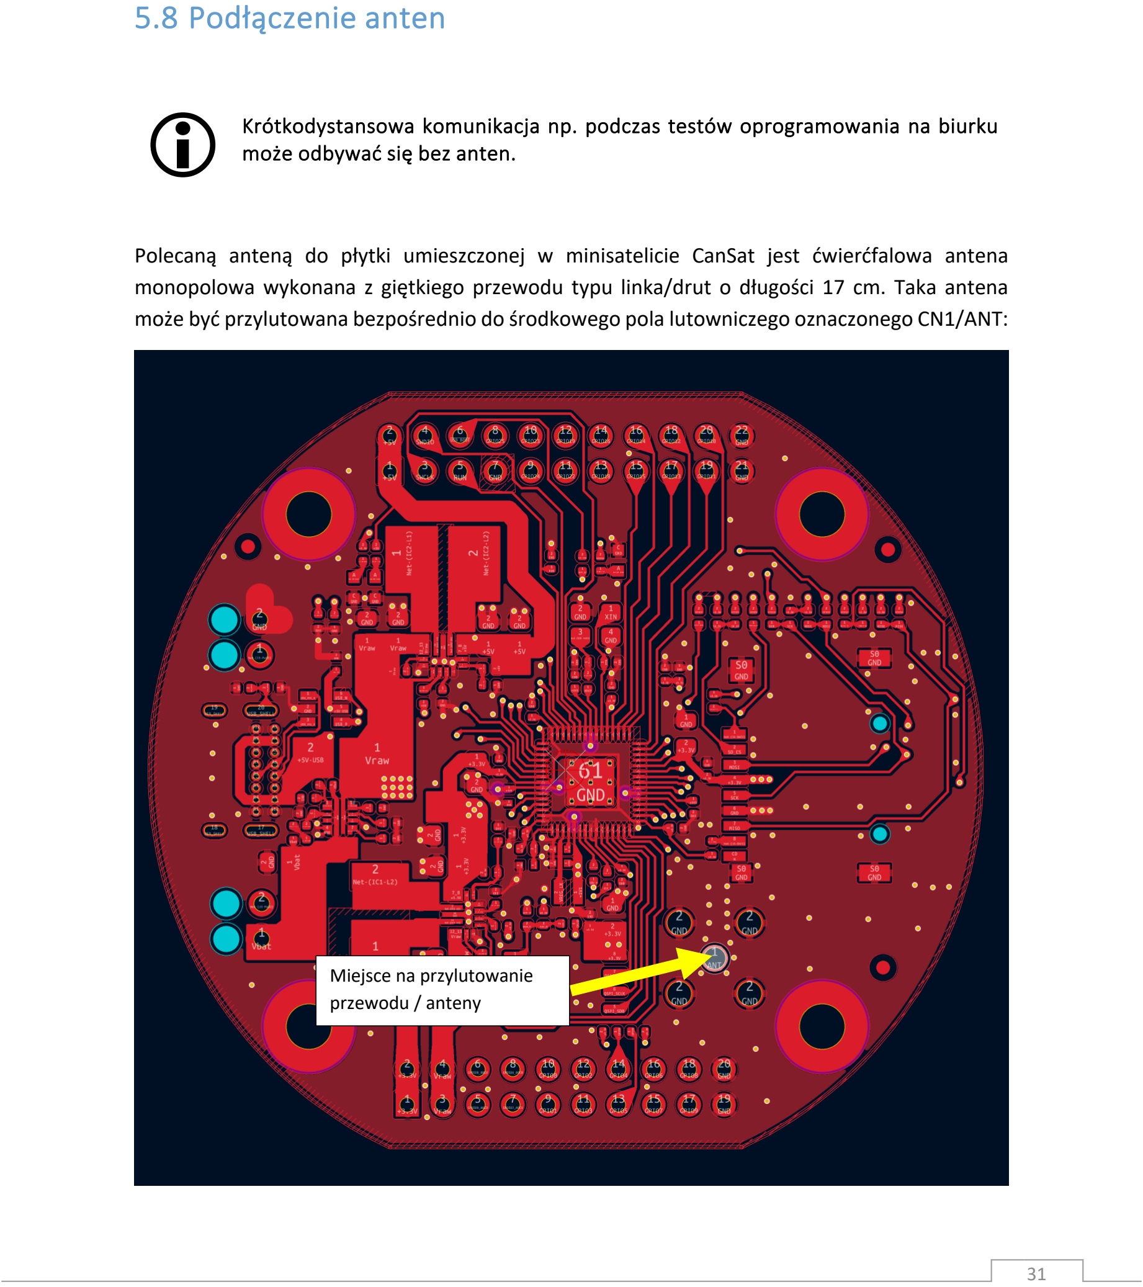
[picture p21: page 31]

🛈 Krótkodystansowa komunikacja np. podczas testów oprogramowania na biurku

może odbywać się bez anten.

Polecaną anteną do płytki umieszczonej w minisatelicie CanSat jest ćwierćfalowa antena monopolowa wykonana z giętkiego przewodu typu linka/drut o długości 17 cm. Taka antena może być przylutowana bezpośrednio do środkowego pola lutowniczego oznaczonego CN1/ANT:

Miejsce na przylutowanie
przewodu / anteny

Przewód należy zabezpieczyć przed ułamaniem w miejscu lutowania - należy zrobić tzw. „stress relief” (https://i.stack.imgur.com/vnF6U.jpg) za pomocą np. kleju epoksydowego lub kleju na gorąco.
Do płytki stacji naziemnej przewidziane jest złącze SMA, które należy wlutować w miejsce CN1/ANT w następujący sposób:

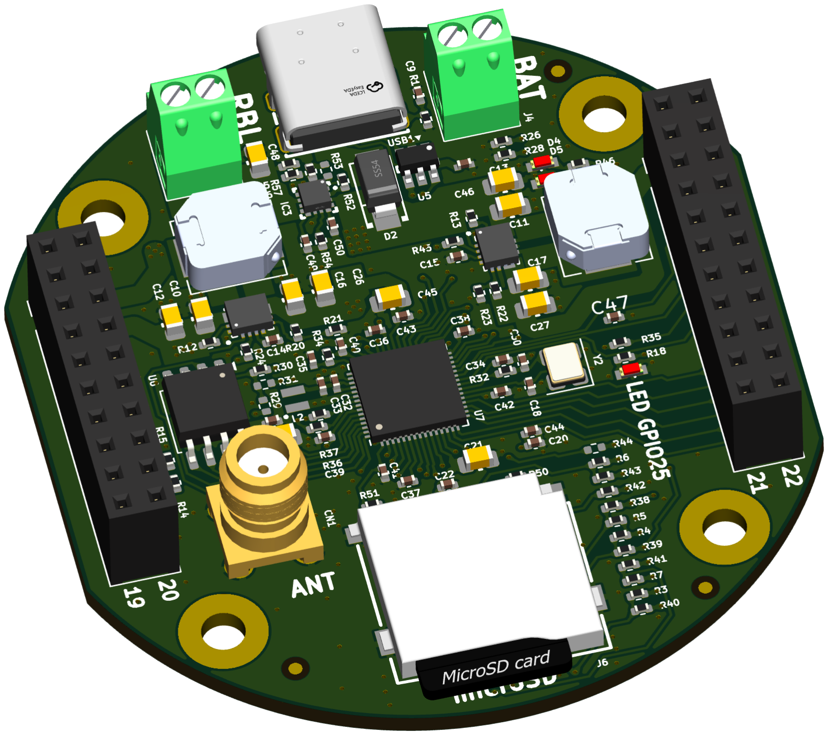
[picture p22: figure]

Do takiego złącza można przyłączyć większą antenę np. typu Yagi-Uda za pomocą standardowego kabla koncentrycznego 50 Ω.

## 5.9 Płytka prototypowa

Płytka prototypowa umożliwia budowę własnych układów i podłączenie ich do płytki głównej. Do płytki prototypowej należy przylutować listwy kołkowe dołączone do zestawu (raster 2.54 mm)

lub inne listwy kołkowe wg potrzeb (np. możliwe jest użycie dłuższych listew kołkowych w celu połączenia większej liczby płytek prototypowych).
Białe linie na płytce prototypowej pokazują połączenia elektryczne. Dzięki temu możliwe jest łatwe i pewne podłączenie zworek pomiędzy własnym układem, a płytką główną.

Pliki źródłowe (format Kicad) są dostępne i mogą posłużyć jako baza do wytworzenia własnych płytek PCB, jednocześnie posiadając gotowe punkty montażowe i podłączenie do płytek głównych CanSat Kit. Pliki produkcyjne (gerber) są dostępne i mogą być wykorzystane do własnej produkcji płytek.

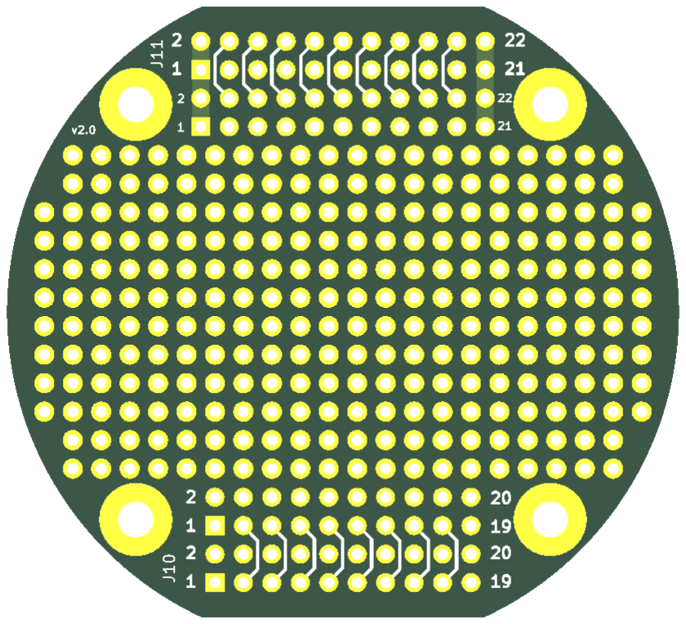
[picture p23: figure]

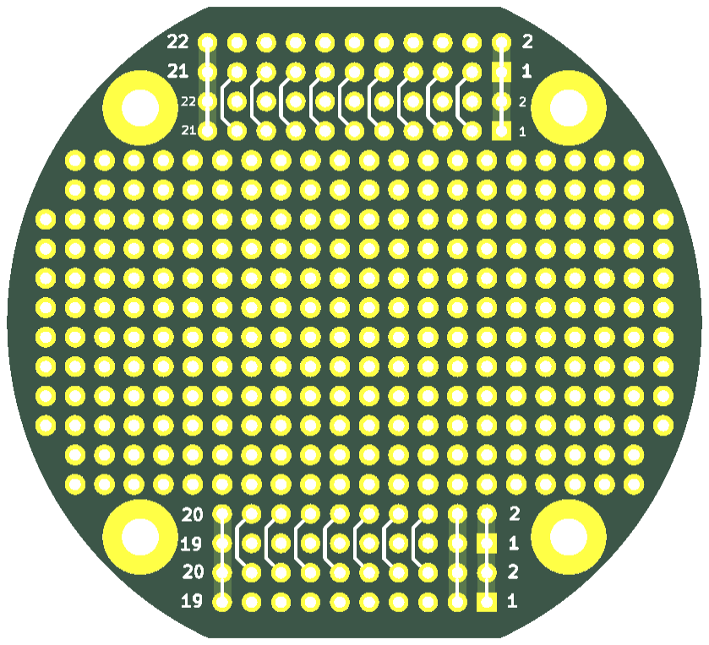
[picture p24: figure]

## 6 Zestaw analogiczny

Zestaw CanSat Kit v2 można funkcjonalnie odtworzyć przy użyciu ogólnodostępnych komponentów i modułów elektronicznych. Prototypowanie, eksperymenty i testy, które mogą spowodować przypadkowe uszkodzenie zestawu CanSat Kit poleca się przeprowadzać na zestawie analogicznym.

## 6.1 Lista elementów zestawu analogicznego

- Raspberry Pi Pico 2 x 2
- Moduł radiowy SX1278 x 2
- Moduł czytnika kart SD x 2
- Moduł czujnika ciśnienia BMP280 x 1
- Czujnik NTC 10k x 1
- Rezystor 10k x 1
- Płytka stykowa x 2

- Kable połączeniowe do płytki stykowej i modułów

## 6.2 Podłączenie modułów

Moduł radiowy należy podłączyć do Raspberry Pi Pico 2 zgodnie z rozdziałem 4.1.6 Moduł radiowy, natomiast czytnik kart micro SD zgodnie z rozdziałem 4.1.5 Czytnik kart microSD. W obu przypadkach należy pamiętać o podłączeniu zasilania zgodnie z wymaganiami zakupionych modułów. Czujniki temperatury NTC 10k i BMP280 należy podłączyć w identyczny sposób jak do płytki głównej CanSat Kit.

## 6.3 Różnice i ograniczenia

!"# Zestaw analogiczny dostarcza takie same poziomy napięć jak zestaw CanSat Kit (3.3 V, 5 V), jednakże wydajność prądowa poszczególnych linii zasilania może być inna, w zależności od zakupionej wersji Raspberry Pi Pico 2 lub jego odpowiednika.

!"# Zestaw analogiczny nie może być zasilany z baterii/akumulatorów o takim samym napięciu jak zestaw CanSat Kit.

!"# Po pomyślnych testach na zestawie analogicznym należy przeprowadzić testy na zestawie CanSat Kit!

!"# Testy zasięgu radiowego powinny być prowadzone na zestawie CanSat Kit ze względu na duży wpływ toru radiowego i anten na osiągi.

## 7 Bezpieczeństwo i zasady prawidłowego użytkowania

1) Zestaw przeznaczony jest do celów edukacyjnych, badawczych i rozwojowych.
2) Użycie zestawu na zewnątrz wymaga zastosowania obudów chroniących przed wilgocią, bezpośrednim kontaktem z wodą, zanieczyszczeniami i pyłem.
3) Zestaw powinien być zasilany zgodnie z instrukcjami zawartymi w niniejszym dokumencie. Nieprawidłowe podłączenie zestawu może doprowadzić do jego uszkodzenia i komponentów podłączonych do zestawu, silnego nagrzania elementów, wzniecenia otwartego ognia, a nawet eksplozji akumulatorów (jeśli były podłączone).
4) Zewnętrzne urządzenia elektroniczne powinny być podłączone do zestawu przez dedykowane do tego złącza wymienione w rozdziale 4.1.2 Mapa złącz, gniazd i diod LED. Podłączanie, lutowanie czy wprowadzanie innych modyfikacji do zestawu skutkuje utratą gwarancji i może doprowadzić do uszkodzenia zestawu. Należy przestrzegać ograniczeń odnośnie użytkowania wyprowadzeń zestawu i podłączania urządzeń zewnętrznych, które są wymienione w niniejszej instrukcji.
5) Zestaw jest czuły na wyładowania elektrostatyczne ESD, które mogą doprowadzić do uszkodzenia części lub całości urządzenia. Zaleca się stosować procedury zmniejszające ryzyko powstawania wyładowań elektrostatycznych (maty, opaski uziemiające itp.).
6) Zestaw nie powinien być użytkowany w przypadku stwierdzenia widocznego uszkodzenia jakiejkolwiek jego części do czasu zweryfikowania wpływu zaistniałego uszkodzenia lub naprawienia usterki.
7) W przypadku stwierdzenia nadmiernego nagrzewania się elementów zestawu, podejrzanego zapachu, pojawienia się dymu lub ognia należy natychmiast odłączyć cały zestaw od wszelkich źródeł zasilania.
8) Elementy zestawu należy czyścić za pomocą suchej lub nasączonej alkoholem izopropylowym antystatycznej ściereczki. Wyjątek stanowi czujnik ciśnienia BMP280, który może być czyszczony tylko ściereczką suchą.
9) Zużyte elementy zestawu powinny zostać zutylizowane zgodnie z obowiązującym prawem, w szczególności nie mogą być wyrzucane wraz z odpadami ogólnymi.

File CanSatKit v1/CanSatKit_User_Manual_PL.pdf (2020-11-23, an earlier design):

# Dokumentacja zestawu startowego CanSat Kit

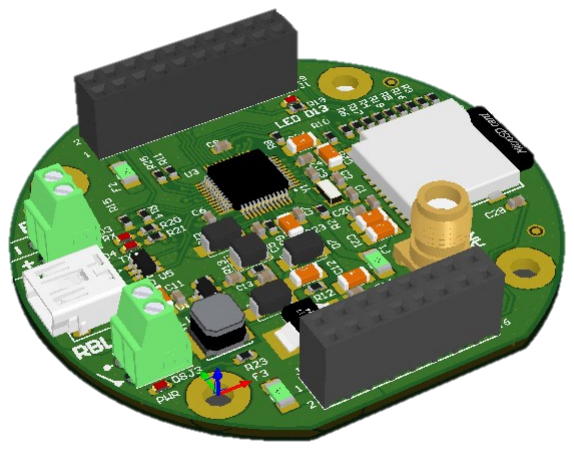
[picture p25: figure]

Rewizja dokumentu: v1.5 (2020-10-26) Dotyczy zestawu CanSat Kit rev. 1.2

# 1 Spis treści

## 2 Przeznaczenie zestawu

Zestaw startowy CanSat Kit zaprojektowany został jako platforma do budowy minisatelity CanSat oraz stacji naziemnej zgodnych z wymaganiami konkursu „CanSats in Europe” oraz polskich zawodów CanSat organizowanych przez ESERO-PL.

Przed użyciem zestawu należy zapoznać się z niniejszym dokumentem, w szczególności z rozdziałem 7. Bezpieczeństwo i zasady prawidłowego użytkowania.

## 3 Elementy zestawu

Zestaw zawiera wszystkie niezbędne komponenty elektroniczne do wypełnienia misji podstawowej minisatelity CanSat: moduł zasilania (bez akumulatora/baterii), komputer pokładowy, moduły łączności bezprzewodowej, a także czujniki temperatury i ciśnienia atmosferycznego.

Obudowa minisatelity CanSat, system odzysku (np. spadochron) oraz akumulator/bateria zasilająca powinny zostać wykonane/dodane przez użytkownika zestawu według wymagań danego minisatelity.

Zestaw CanSat Kit składa się z następujących elementów:

- 2 x płytka główna CanSata / stacji naziemnej
- 1 x płytka drukowana prototypowa
- 1 x czujnik temperatury LM35
- 1 x czujnik ciśnienia BMP280
- 2 x kabel mini USB
- 1 x złącze antenowe SMA
- 1 x listwa kołkowa 2x40-pin 2.54 mm
- 2 x złącze śrubowe typu terminal block 2.54 mm
- 1 x płytka stykowa

- 8 x kabel do płytki stykowej
- 1 x opakowanie ESD

## 4 Parametry techniczne

## 4.1 Płytka główna CanSata / stacji naziemnej

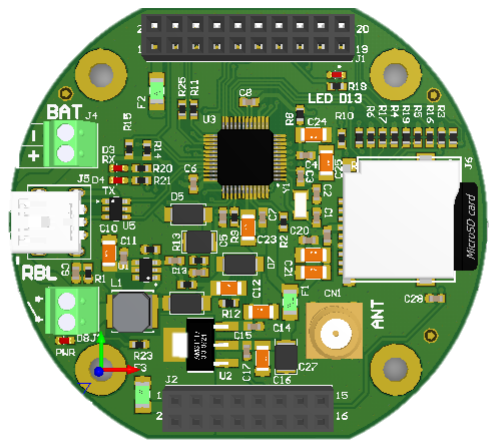
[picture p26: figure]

## 4.1.1 Informacje ogólne

Płytka główna dedykowana jest do użycia zarówno w minisatelicie CanSat, jak i w stacji naziemnej do odbioru danych drogą radiową.

Płytka główna składa się z następujących bloków:

- układ zasilania – umożliwia zasilenie płytki i urządzeń zewnętrznych z pojedynczego ogniwa baterii litowo-jonowej lub innych ogniw o napięciach 2.5 – 5.0 V;
- komputer pokładowy – mikrokontroler zgodny z Arduino M0, z możliwością programowania przez port USB;
- magazyn danych – złączę na kartę microSD, dostępne z poziomu komputera pokładowego;
- moduł łączności bezprzewodowej – układ radiowy nadawczo-odbiorczy, oparty o standard LoRa, z zewnętrznym złączem antenowym.

## 4.1.2 Mapa złącz, gniazd i diod LED

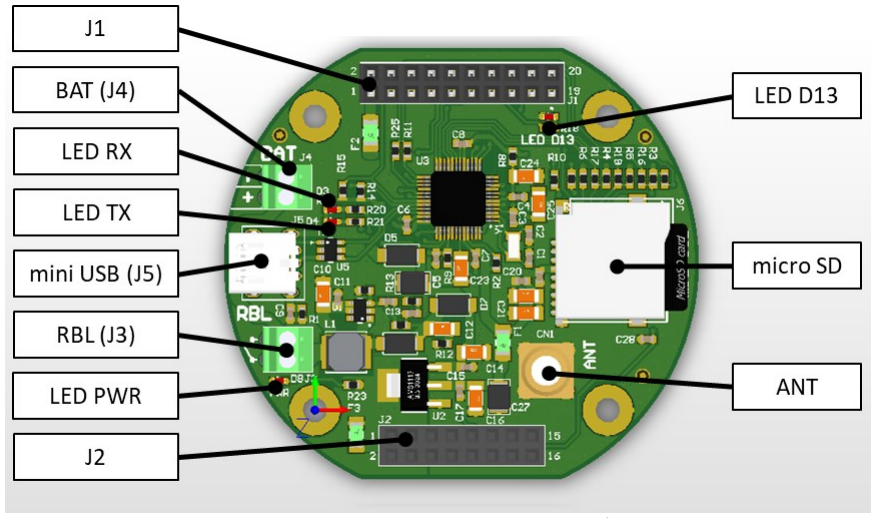
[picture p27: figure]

Tabela 1. Złącza, gniazda i diody LED płytki głównej / stacji naziemnej

Nazwa złącza | Opis i funkcje
BAT (J4) | • złącze zasilania zewnętrznego (np. z baterii): 2.5 – 5.0 V, • raster 2.5 mm, • możliwość wlutowania złącza typu listwa kołkowa (header), śrubowego (terminal block) lub przylutowania przewodów (ze stress reliefem). (https://cdn.sparkfun.com/assets/5/3/b/f/2/526d7970757b7f7f708b4568.jpg)
RBL (J3) | • zworka zasilania, • możliwość wpięcia głównego włącznika,
mini USB (J5) | • zasilanie, • programowanie mikrokontrolera z Arduino IDE, • przesyłanie danych (SerialUSB), • po więcej szczegółów zobacz dokumentację Arduino M0 dotyczącą złącza USB.
J1, J2 | • złącze kołkowe żeńskie 2.5 mm, • dostępne napięcia zasilające, • wyprowadzone wejścia/wyjścia mikrokontrolera.
micro SD | • złącze na karty pamięci micro SD, • podłączone do mikrokontrolera – zob. 4.1.6.
ANT | • złącze anteny modułu radiowego, • możliwość przylutowania złącza SMA (https://media.rs-online.com/t_large/F6163422-01.jpg) np. do wkręcenia większej anteny (w stacji naziemnej), • możliwość przylutowania anteny ćwierćfalowej wykonanej z przewodu.

4.1.2.1 Złącze J1

🛈

Piny zaznaczone (✓) jako „Arduino M0” są w pełni kompatybilne z płytką Arduino M0. Szczegółowe informacje o właściwościach i wykorzystaniu tych pinów są dostępne w dokumentacji Arduino M0: https://store.arduino.cc/arduino-m0

Standard napięć dla pinów mikrokontrolera to 3.3 V.
Podłączenie urządzeń pracujących w innych standardach napięciowych (np. 5 V) może skutkować uszkodzeniem zestawu.

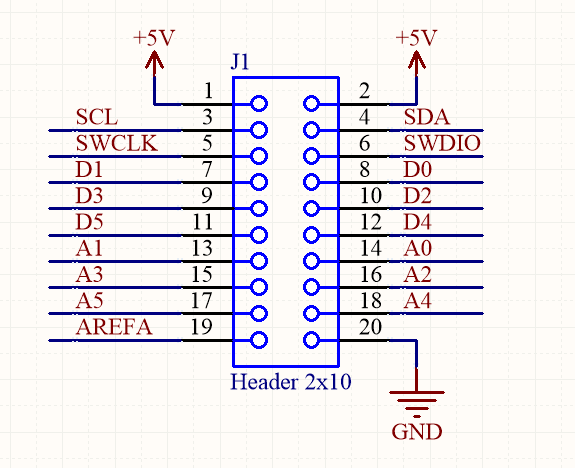
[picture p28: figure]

Tabela 2. Mapa pinów złącza J1

Pin nr | Nazwa | Arduino
M0 | Opis

Użycie w Arduino IDE

wejście (https://www.arduino.cc/reference/en/language/functions/digital-io/digitalread/) / wyjście (https://www.arduino.cc/reference/en/language/functions/digital-io/digitalwrite/) cyfrowe | wejście analogowe (https://www.arduino.cc/reference/en/language/functions/analog-io/analogread/) | wyście analogowe (https://www.arduino.cc/reference/en/language/functions/analog-io/analogwrite/) | inne funkcje
1 | +5 V | | Zasilanie + 5 V | - | - | - | -
2 | +5 V | | Zasilanie + 5 V | - | - | - | -
3 | SCL² | ✓ | Interfejs I2C – linia SCL (clock) | 17 | - | - | I2C – Wire lib (https://www.arduino.cc/en/Reference/Wire)
4 | SDA² | ✓ | Interfejs I2C – linia SDA (data) | 16 | - | - | I2C – Wire lib (https://www.arduino.cc/en/Reference/Wire)
5 | SWCLK | | pin do programowania przy użyciu zewnętrznego programatora | - | - | - | -
6 | SWDIO | | pin do programowania przy użyciu zewnętrznego programatora | - | - | - | -
7 | D1 | ✓ | Generalnego przeznaczenia – wejście/wyjście cyfrowe (GPIO) Serial port TX: w Arduino IDE jako Serial1 | 1 | - | - | Serial1 (TX)
8 | D0 | ✓ | Generalnego przeznaczenia – wejście/wyjście cyfrowe (GPIO) Serial port RX: w Arduino IDE jako Serial1 | 0 | - | - | Serial1 (RX)
9 | D3 | ✓ | Generalnego przeznaczenia – wejście/wyjście cyfrowe (GPIO) | 3 | - | 3 | -
10 | D2 | ✓ | Generalnego przeznaczenia – wejście/wyjście cyfrowe (GPIO) | 2 | - | 2 | -

11 D5 | ✓ | Generalnego przeznaczenia – wejście/wyjście cyfrowe (GPIO) | 5 | - | 5 | -
12 D4 | ✓ | Generalnego przeznaczenia – wejście/wyjście cyfrowe (GPIO) | 4 | - | 4 | -
13 A1 | ✓ | Wejście/wyjście cyfrowe (GPIO), wejście analogowe (ADC) | A1 | A1 | - | -
14 A0 | ✓ | Wejście/wyjście cyfrowe (GPIO), wejście analogowe (ADC), wyjście analogowe (DAC) | A0 | A0 | A0 | -
15 A3 | ✓ | Wejście/wyjście cyfrowe (GPIO), wejście analogowe (ADC) | A3 | A3 | - | -
16 A2 | ✓ | Wejście/wyjście cyfrowe (GPIO), wejście analogowe (ADC) | A2 | A2 | - | -
17 A5 | ✓ | Wejście/wyjście cyfrowe (GPIO), wejście analogowe (ADC) | A5 | A5 | - | -
18 A4 | ✓ | Wejście/wyjście cyfrowe (GPIO), wejście analogowe (ADC) | A4 | A4 | - | -
19 AREFA | ✓ | Zewnętrzne napięcie referencyjne (https://blog.arduino.cc/2010/12/13/tutorial-arduino-and-the-aref-pin/) dla przetwornika ADC (opcjonalnie) | - | - | - | -
20 GND | ✓ | Masa | - | - | - | -

4.1.2.2 Złącze J2
🛈

Piny zaznaczone (✓) jako „Arduino M0” są w pełni kompatybilne z płytką Arduino M0. Szczegółowe informacje o właściwościach i wykorzystaniu tych pinów są dostępne w dokumentacji Arduino M0: https://store.arduino.cc/arduino-m0

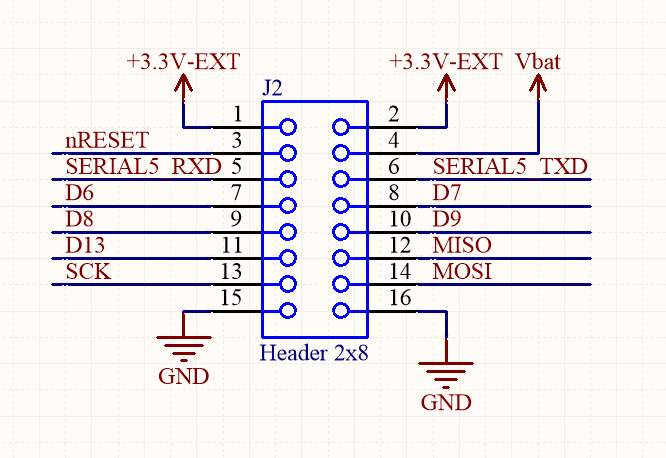
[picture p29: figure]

Tabela 3. Mapa pinów złącza J2

Pin nr | Nazwa | Arduino
M0 | Opis

Użycie w Arduino IDE

wejście (https://www.arduino.cc/reference/en/language/functions/digital-io/digitalread/) / wyjście (https://www.arduino.cc/reference/en/language/functions/digital-io/digitalwrite/) cyfrowe | wejście analogowe (https://www.arduino.cc/reference/en/language/functions/analog-io/analogread/) | wyście analogowe (https://www.arduino.cc/reference/en/language/functions/analog-io/analogwrite/) | inne funkcje
1 | +3.3 V | | Zasilanie + 3.3 V | - | - | - | -
2 | +3.3 V | | Zasilanie + 3.3 V | - | - | - | -
3 | nRESET | ✓ | Zanegowany reset mikrokontrolera (zwarcie z GND powoduje reset mikrokontrolera) | - | - | - | -
4 | Vbat | | Napięcie z wejścia Vbat (za zworką RBL) | - | - | - | -
5 | SERIAL5_RXD | ✓¹ | Dodatkowy Serial port RX: w Arduino IDE jako Serial | - | - | - | Serial (RX)
6 | SERIAL5_TXD | ✓¹ | Dodatkowy Serial port TX: w Arduino IDE jako Serial | - | - | - | Serial (TX)
7 | D6 | ✓ | Generalnego przeznaczenia – wejście/wyjście cyfrowe (GPIO) | 6 | - | - | -
8 | D7 | ✓ | Generalnego przeznaczenia – wejście/wyjście cyfrowe (GPIO) | 7 | - | - | -
9 | D8 | ✓ | Generalnego przeznaczenia – wejście/wyjście cyfrowe (GPIO) | 8 | - | - | -
10 | D9 | ✓ | Generalnego przeznaczenia – wejście/wyjście cyfrowe (GPIO) | 9 | - | - | -
11 | D13 | ✓ | Generalnego przeznaczenia – wejście/wyjście cyfrowe (GPIO), podłączona dioda D13 | 13 | - | - | -

12 | MISO² | ✓ | Interfejs SPI, podłączony czytnik kart SD oraz moduł radiowy | 18 | - | - | -
13 | SCK² | ✓ | Interfejs SPI, podłączony czytnik kart SD oraz moduł radiowy | 20 | - | - | -
14 | MOSI² | ✓ | Interfejs SPI, podłączony czytnik kart SD oraz moduł radiowy | 21 | - | - | -
15 | GND | ✓ | Masa | - | - | - | -
16 | GND | ✓ | Masa | - | - | - | -

Przypisy:

1 – dostępne na Arduino M0 w wersji Wemos SAMD21 M0 (https://startingelectronics.org/articles/arduino/wemos-arduino-m0/)

2 – do linii podłączono rezystor podciągający do 3.3 V (pull-up) o rezystancji 15 kΩ

4.1.2.3 Diody

Tabela 4. Diody świecące (LED) dostępne na płytce i ich funkcje

Nazwa diody | Opis
LED D13 | • dioda LED bezpośrednio podłączona do pinu D13 mikrokontrolera, • kompatybilna z diodą D13 w Arduino M0 (LED_BUILTIN), • po więcej szczegółów zobacz dokumentację Arduino M0.
LED PWR | • dioda sygnalizująca obecność napięcia na linii zasilania 3.3 V, • obecność napięcia na linii 3.3 V implikuje obecność na linii 5 V (oraz VBAT, jeśli zasilanie jest dostarczane przez VBAT).
LED RX | • aktywna, gdy płytka odbiera dane przez port SerialUSB (więcej szczegółów w dokumentacji Arduino M0)
LED TX | • aktywna, gdy płytka wysyła dane przez port SerialUSB (więcej szczegółów w dokumentacji Arduino M0)

## 4.1.3 Źródła i metody zasilania płytki

Płytka główna może być zasilana na kilka różnych sposobów, które zostały przedstawione poniżej:

1) Złącze zasilające J4 (BAT)
̶ minimalne napięcie wejściowe: 2.5 V
̶ maksymalne napięcie wejściowe: 5.0 V
̶ zasilenie układów płytki ze złącza BAT następuje tylko wtedy, gdy zwarta jest zworka oznaczona jako RBL,
̶ zalecane jest zasilanie płytki z akumulatorów litowo-jonowych (1 cela szeregowo/1S, 3.7 -4.3 V), baterii lub akumulatorów 3 x AA/AAA połączone szeregowo (3.6 – 4.5 V).
2) Złącze mini USB (J5)
̶ maksymalne napięcie wejściowe: 5.5 V
̶ podłączenie płytki za pomocą złącza mini USB spowoduje zasilenie jej modułów (w tym pojawienie się napięcia na liniach zasilających 5 V i 3.3 V na złączu J1 i J2) niezależnie od stanu zworki RBL.
3) Złącze kołkowe J2: VBAT (pin 4) oraz GND (piny 15 lub 16)
̶ minimalne napięcie wejściowe: 2.5 V

̶ maksymalne napięcie wejściowe: 5.0 V
̶ podłączenie płytki za pomocą tego złącza spowoduje zasilenie jej modułów (w tym pojawienie się napięcia na liniach zasilających 5 V i 3.3 V na złączu J1 i J2) niezależnie od stanu zworki RBL.

Zamiana polaryzacji zasilania powoduje nieodwracalne uszkodzenia na płytce!

Podłączenie napięcia większego niż maksymalne napięcie podane w specyfikacji dla danego wejścia może spowodować nieodwracalne uszkodzenia na płytce!

## 4.1.4 Układ zasilania

Układ zasilania obecny na płytce odpowiada za konwersję energii elektrycznej, dystrybucję na płytce głównej do zasilania jej podzespołów oraz dostarczenie energii do zasilenia układów dołączanych do płytki głównej przez użytkownika.

Układ dostarcza następujące linie zasilania na złączach J1 i J2:

- linia 5 V
− napięcie (minimalne, nominalne, maksymalne): 4.7 V, 5.0 V, 5.4 V − wydajność prądowa: maksymalnie 0.75 A, zalecana 0.5 A
- linia 3.3 V
− napięcie (minimalne, maksymalne): 3.0 V, 3.3 V
− wydajność prądowa: maksymalnie 0.75 A, zalecana 0.5 A
- linia VBAT
− bezpośrednie, niezabezpieczone napięcie z baterii (za zworką RBL).

Sumaryczny pobór prądu z linii 3.3 V i 5 V nie może przekraczać 1 A.

W przypadku poboru większego prądu niż podano w specyfikacji dla danej linii, zostanie aktywowane zabezpieczenie nadprądowe, które skutkuje odłączeniem linii na pewien okres. Cała płytka powinna zostać odłączona od zasilania na kilka minut, aby przywrócić napięcie na odłączonej linii. Zabezpieczenie prądowe jest realizowane za pomocą bezpieczników typu „polyfuse”.

Zworka RBL

Zworka RBL jest podłączona szeregowo ze pinem „+” złącza BAT (J4). Zalecane jest podłączenie przełącznika do złącza RBL (J3), który będzie pełnił funkcję głównego włącznika CanSata. Jeśli przełącznik jest zlokalizowany w innym miejscu, złącze RBL (J3) można zewrzeć na stałe.

Zworka ma wpływ tylko i wyłącznie za odłączanie/włączanie źródła zasilania podpiętego do złącza BAT (J4). Nie ma ona wpływu, jeśli płytka zasilana jest przez złącze miniUSB (J5) oraz przez pin VBAT na złączu J2!

## 4.1.5 Mikrokontroler

Adel ATSAMD21G18 to wydajny, 32-bitowy mikrokontroler z rdzeniem ARM Cortex® M0. W 100% zgodny z Arduino M0. (https://store.arduino.cc/arduino-m0)

Parametry techniczne:

Mikrokontroler | ATSAMD21G18, LQFP 48
Architektura rdzenia | ARM Cortex-M0+
Napięcie pracy | 3.3V
Pamięć Flash | 256 KB
Pamięć SRAM | 32 KB
Częstotliwość zegara | 48 MHz

Dostępne dla użytkownika interfejsy zostały wymienione w tabelach 4.1.2.1 oraz 4.1.2.2.

Pobór prądu z każdego pinu mikrokontrolera:
- maksymalnie 10 mA
- rekomendowane 7 mA

Sumaryczny pobór prądu z pinów w obrębie jednej grupy zasilania maksymalnie 65 mA. Zobacz dokumentację mikrokontrolera. (https://www.microchip.com/wwwproducts/en/ATSAMD21G18)

Sumaryczny pobór prądu ze wszystkich pinów mikrokontrolera maksymalnie 130 mA. Zobacz dokumentację mikrokontrolera. (https://www.microchip.com/wwwproducts/en/ATSAMD21G18)

## 4.1.6 Czytnik kart microSD

Czytnik kart microSD został podłączony do mikrokontrolera poprzez interfejs SPI, zgodnie z poniższą tabelą.

Pin karty SD (funkcja w trybie SPI karty SD) | Pin mikrokontrolera
DAT0 (MISO) | MISO
CMD (MOSI) | MOSI
CLK (Clock / SCK) | SCK
DAT3 (Chip Select / CS) | D11
🛈
Więcej informacji o podłączaniu karty SD do Arduino można znaleźć w dokumentacji biblioteki (https://www.arduino.cc/en/Reference/SD) oraz poradniku. (https://www.arduino.cc/en/Reference/SDCardNotes)

## 4.1.7 Moduł radiowy

Moduł radiowy SX1278 został podłączony do mikrokontrolera poprzez interfejs SPI oraz dodatkowe piny GPIO, zgodnie z poniższą tabelą:

Pin modułu SX1278 | Pin mikrokontrolera
MISO | MISO
MOSI | MOSI
SCK | SCK
NSS | D10
RESET | nRESET

DIO0 | D12
DIO1 | D9 1

Przypisy:

1
– domyślnie pin DIO1 nie jest podłączony do pinu mikrokontrolera D9, aby to zrobić należy wlutować rezystor R10 - wielkość SMD0603 o wartości 0 - 100 Ω lub zworkę np. kawałek drutu. Nie jest to jednak niezbędne do wykonania misji CanSata, instrukcja przez cały czas zakłada, że pin jest odłączony.
🛈
Szczegółowe informacje o module radiowym SX1278 można znaleźć w jego dokumentacji. (https://cdn-shop.adafruit.com/product-files/3179/sx1276_77_78_79.pdf)

## 4.1.8 Parametry mechaniczne

Kształt płytki: koło o promieniu 30 mm ze ściętymi fragmentami – w miejscu ścięcia szerokość 54.4 mm.

Na płytce rozmieszczone są 4 otwory montażowe przeznaczone na śruby M3 (średnica 3.2 mm). Otwory posiadają metalizowane obręcze (średnica 6.5 mm), podłączone bezpośrednio do masy (GND).

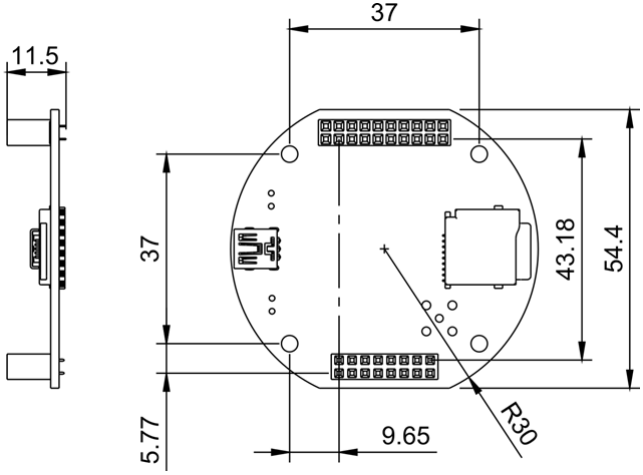
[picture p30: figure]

Masy poszczególnych elementów zestawu zebrane są w tabeli:

Element | Masa
Płytka główna | 18 g
Płytka prototypowa + złącza goldpin | 10 g
Czujnik ciśnienia | 1 g

## 4.2 Czujnik temperatury

🛈
Szczegółowe informacje o czujniku temperatury LM35 można znaleźć w jego dokumentacji. (http://www.ti.com/lit/ds/symlink/lm35.pdf)

## 4.2.1 Parametry pomiarowe

- 0.5 °C dokładności (w temperaturze 25 °C)
- Dostosowany do zakresu temperatur −55 °C to 150 °C
- Niskie samoogrzewanie (self-heating), 0.08 °C w stojącym powietrzu
- Nielinowość pomiaru ±¼ °C (typowo)

## 4.2.2 Zasilanie

- zakres napięcia zasilania: 4 V – 20 V
- pobór prądu: 60 μA

## 4.2.3 Interfejs

LM35 jest czujnikiem analogowym. Informacja o mierzonej temperaturze zakodowana jest w postaci napięcia wyjściowego obecnego na pinie nr 2 czujnika, zgodnie z równaniem:

Vout = T [℃] ⋅ 10 [mV/℃]

gdzie T [℃] jest mierzoną temperaturą.

## 4.2.4 Pinout

Poniższy obrazek pokazuje identyfikację pinów czujnika LM35:

### 1. VCC 2. OUT 3. GND

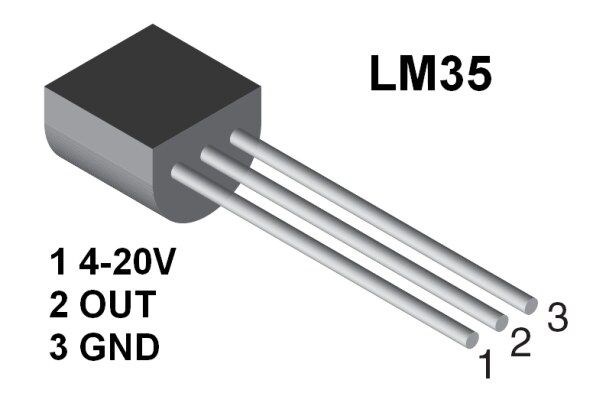
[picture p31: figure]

## 4.2.5 Parametry mechaniczne

Czujnik posiada obudowę plastikową typu TO-92 z trzema wyprowadzeniami. Przybliżone wymiary czujnika przedstawione są w dokumentacji obudowy TO-92 (http://www.ti.com/lit/ds/symlink/lm35.pdf) (strony 29-30).

## 4.3 Czujnik ciśnienia atmosferycznego

🛈
Szczegółowe informacje o czujniku ciśnienia atmosferycznego BMP280 można znaleźć w jego dokumentacji. (https://www.bosch-sensortec.com/products/environmental-sensors/pressure-sensors/pressure-sensors-bmp280-1.html)

## 4.3.1 Parametry pomiarowe

- Zakres pomiaru ciśnienia: 300 - 1100 hPa
- Zakres pomiaru temperatury: od –40 - 85 °C
- Dokładność bezwzględna (0 - 65 °C): ±1 hPa
- Dokładność względna (700 – 900 hPa przy +25 °C do +40 °C): ± 0.12 hPa (odpowiada ±1 m)
- Czas pomiaru: od 5.5 ms

## 4.3.2 Zasilanie

- zakres napięcia zasilania: 1.71 V – 3.6 V
- pobór prądu: < 1 mA

## 4.3.3 Interfejs

- komunikacja z mikrokontrolerem poprzez cyfrowy interfejs I2C (linie SDA i SCL)
- adres I2C czujnika: 0x76
- zarówno mikrokontroler, jak i czujnik na swojej płytce posiadają odpowiednie rezystory podciągające linie SDA i SCL (pull-up), wymagane do prawidłowej pracy interfejsu I2C
- alternatywnie możliwość użycia interfejsu SPI – szczegóły dostępne w dokumentacji czujnika

## 4.3.4 Pinout

Pogrubione skróty obecne są na spodniej stronie płytki czujnika:

- VCC - Napięcie zasilania 3.3 V
- GND - Masa
- SCL - Zegar I2C / SPI
- SDA - Linia danych I2C / MOSI w trybie SPI
- CSB - Chip Select (standardowo nieużywany, nieprzylutowany)
- SD0 - MISO w trybie SPI (standardowo nieużywany, nieprzylutowany)

## 4.3.5 Parametry mechaniczne

- Czujnik jest przylutowany do niewielkiej płytki PCB ze złączem w postaci listwy kołkowej 6-pin o rastrze 2.54 mm.
- Dostępne są również dwa otwory montażowe o średnicy 3 mm.
- Rozmiar płytki: 15 x 10 mm
- Masa: 0.6 g

## 5 Uruchomienie zestawu

## 5.1 Instalacja i konfiguracja środowiska Arduino IDE

1) Pobierz program Arduino IDE w wersji desktop przynajmniej 1.8.5 ze strony https://www.arduino.cc/en/main/software dla swojego systemu operacyjnego.
2) Zainstaluj oprogramowanie zgodnie z instrukcjami dla swojego systemu operacyjnego: https://www.arduino.cc/en/Guide/HomePage .
3) Uruchom Arduino IDE i przejdź do opcji: „Tools → Board: … → Boards Manager…”.

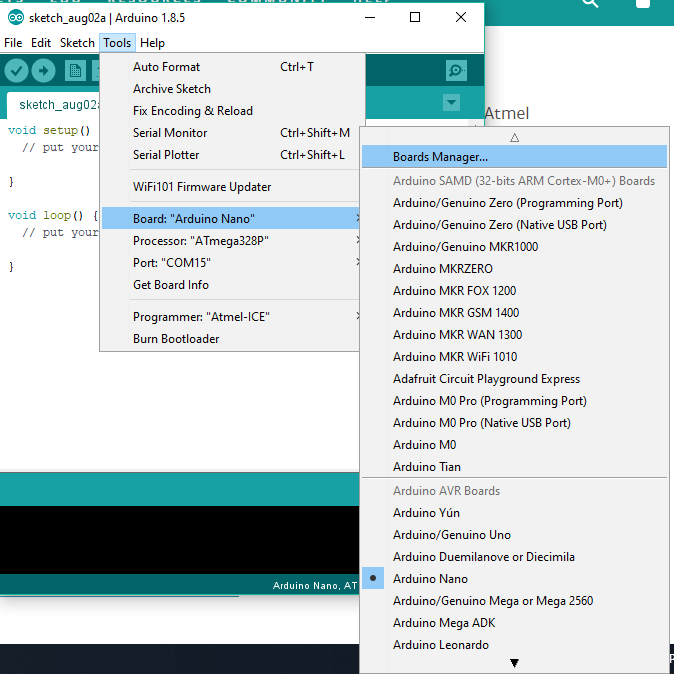
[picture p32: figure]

4) W oknie „Boards Manager” wyszukaj “SAMD” i zainstaluj paczkę „Arduino SAMD Boards (32-bits ARM Cortex-M0+)” w najnowszej wersji i zamknij okno.

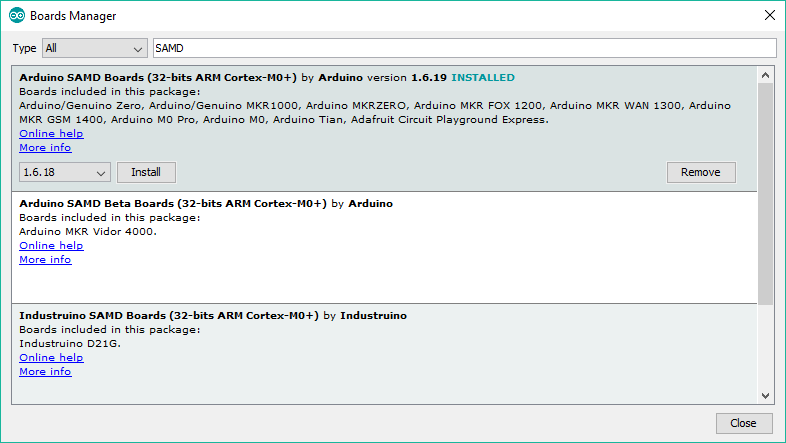
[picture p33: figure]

5) Po zainstalowaniu pakietu płytek Arduino SAMD należy wybrać rodzaj płytki, która będzie używana – w menu „Tools → Board → Arduino M0”.

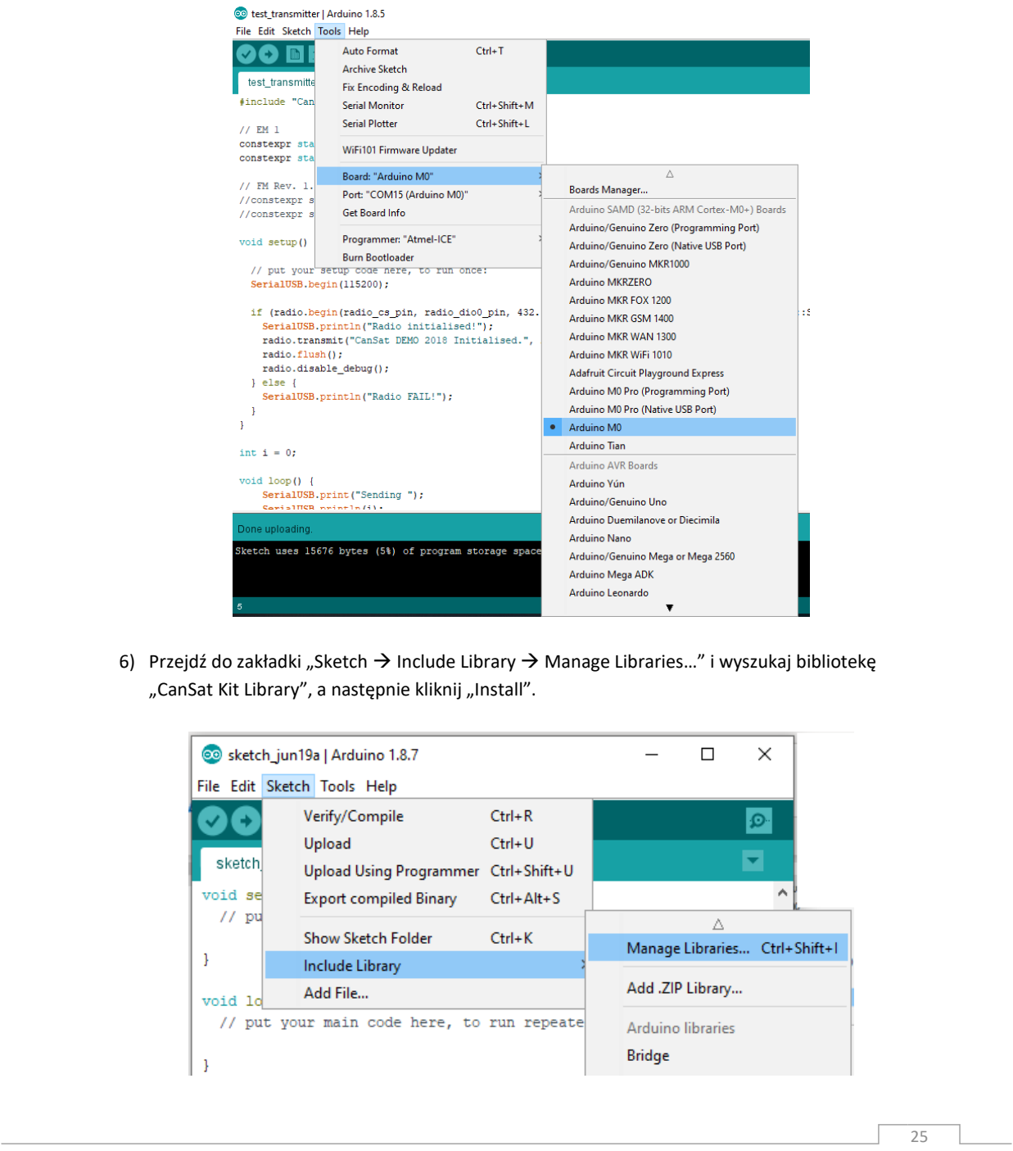
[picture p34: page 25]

6) Przejdź do zakładki „Sketch → Include Library → Manage Libraries…” i wyszukaj bibliotekę „CanSat Kit Library”, a następnie kliknij „Install”.

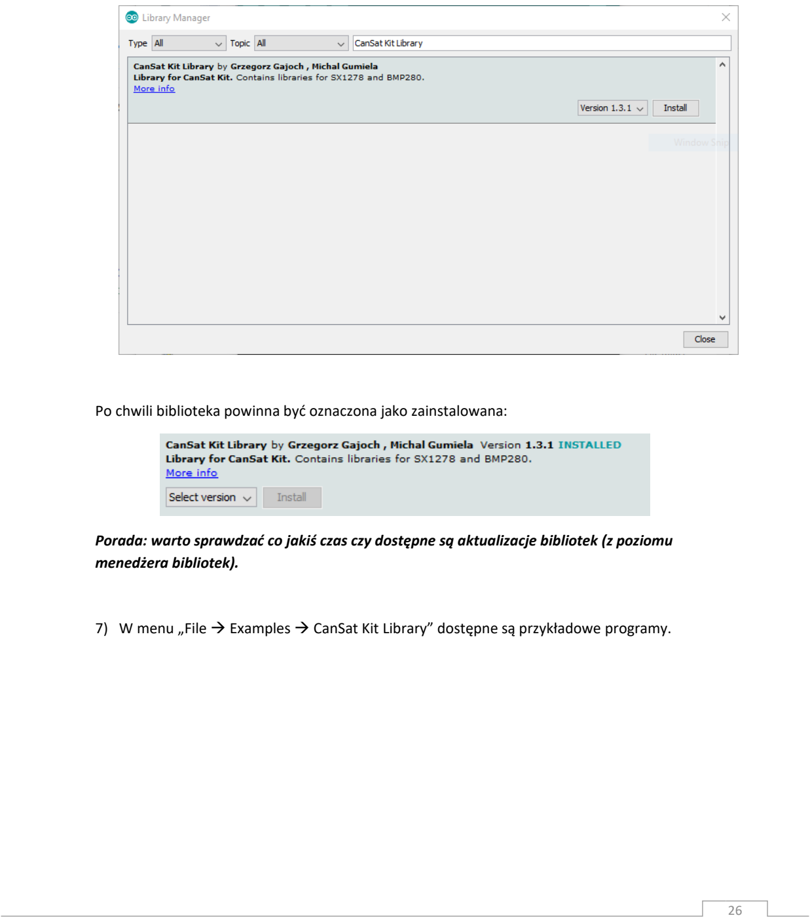
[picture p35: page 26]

Po chwili biblioteka powinna być oznaczona jako zainstalowana:

Porada: warto sprawdzać co jakiś czas czy dostępne są aktualizacje bibliotek (z poziomu menedżera bibliotek).

7) W menu „File → Examples → CanSat Kit Library” dostępne są przykładowe programy.

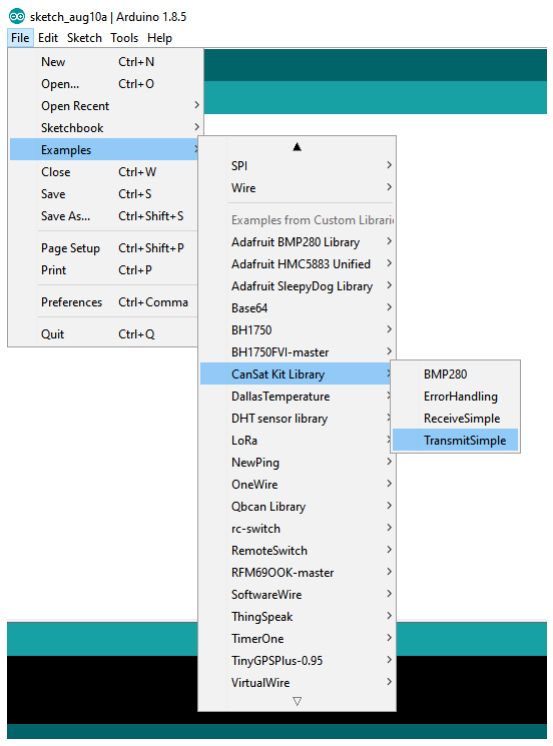
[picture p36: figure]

## 5.2 Podłączanie płytki do komputera za pomocą portu USB

1) Używając kabla mini USB dołączonego do zestawu podłącz jedną z płytek głównych CanSat Kit do komputera PC.
2) W menu „Tools → Port” powinna być widoczna płytka Arduino M0 pod nazwą „COMx (Arduino M0)”. Po wybraniu tego portu możliwe będzie programowanie i komunikacja z podłączoną płytką.

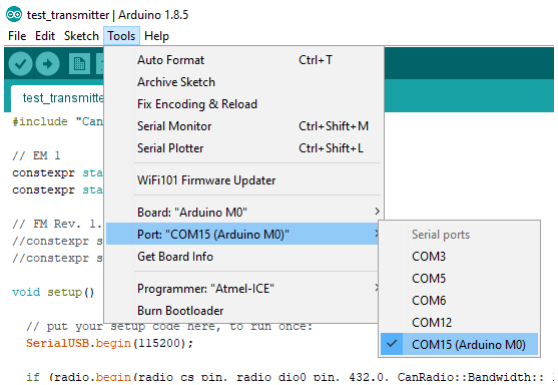
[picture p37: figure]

## 5.3 Wgranie pierwszego programu „Hello CanSat”

1) Otwórz przykładowy program „File → Examples → CanSatKit → HelloCanSatKit”
2) Upewnij się, że płytka jest podłączona do komputera, a Arduino IDE ustawione jest zgodnie z punktami 5.1 5) oraz 5.2.
3) Po wciśnięciu przycisku „Upload” (na pierwszym rysunku poniżej) rozpocznie się kompilacja i wgrywanie oprogramowania na płytkę (drugi rysunek):

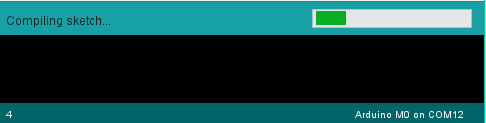
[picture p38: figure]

Proces wgrywania jest sygnalizowany przez miganie niebieskiej diody D13.

4) Po zakończeniu wgrywania (jak na rysunku poniżej) nowy program jest wykonywany przez płytkę CanSat Kit.

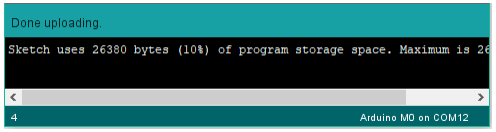
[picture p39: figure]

5) Ostatnim krokiem jest weryfikacja działania programu.
̶ Dioda LED D13 powinna migać co 1 sekundę.
̶ Po otwarciu Monitora Portu Szeregowego (Serial Monitor): „Tools → Serial Monitor” lub ikona lupy w prawym, górnym rogu Arduino IDE na ekranie powinny wyświetlać się komunikaty przesyłane do komputera przez płytkę CanSat Kit.
Uwaga! Należy upewnić się, że wybrana jest prędkość „115200 baud” – jak pokazano na obrazku poniżej:

Uwaga! Po wgraniu oprogramowania może zmienić się numer portu COM – aby otworzyć „Serial Monitor” może okazać się konieczne ponowne wybranie portu - patrz 5.2 pkt. 2).

Wynik działania programu jest widoczny na obrazku poniżej:


## 5.4 Podłączenie i testy czujnika temperatury

1) Podłącz czujnik temperatury do płytki CanSat Kit w następujący sposób:
Piny płytki CanSat Kit | Piny czujnika LM35
+5 V | (1) Vcc
A0 | (2) OUT
GND | (3) GND
2) Otwórz przykładowy program „File → Examples → CanSatKit → TemperatureSensor” i wgraj go na płytkę.
3) Po otwarciu Monitora Portu Szeregowego (Serial Monitor) na ekranie wyświetlone zostaną pomiary temperatury. Alternatywnie można otworzyć aplikację „Kreślarka”: „Tools → Serial Plotter” (lub kombinacja klawiszy Ctrl-Shift-L).


## 5.5 Podłączenie i testy czujnika ciśnienia

1) Podłącz czujnik ciśnienia do płytki CanSat Kit w następujący sposób:
Piny płytki CanSat Kit | Piny czujnika ciśnienia BMP280
+3.3 V | VCC
GND | GND
SCL | SCL
SDA | SDA
2) Otwórz przykładowy program „File → Examples → CanSatKit → PressureSensor” i wgraj go na płytkę.
3) Po otwarciu Monitora Portu Szeregowego (Serial Monitor) na ekranie wyświetlone zostaną pomiary ciśnienia. Alternatywnie można otworzyć aplikację „Kreślarka”: „Tools → Serial Plotter” (lub kombinacja klawiszy Ctrl-Shift-L).


## 5.6 Używanie karty micro SD

Do uruchomienia tego przykładu konieczne będzie włożenie karty pamięci micro SD do odpowiedniego slotu na płytce. Polecane jest używanie kart o niewielkich rozmiarach np. 128 MB – 8 GB.

1) Włóż kartę micro SD do slotu na płytce (stykami karty SD do płytki), podłącz płytkę kablem USB do komputera.
2) W środowisku Arduino IDE otwórz przykład Datalogger: „File → Examples → SD → Datalogger”.

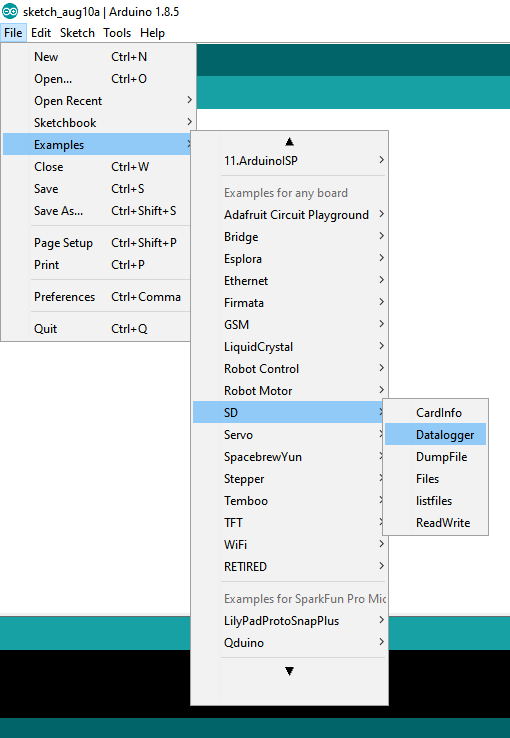
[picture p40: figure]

3) Dokonaj niezbędnych modyfikacji w programie:

̶ stałą const int chipSelect = 4; zamień na const int chipSelect = 11;
̶ wszystkie wystąpienia wyrazu Serial zamień na SerialUSB.
4) Skompiluj i wgraj program na płytkę.
5) Otwórz monitor portu szeregowego i obserwuj dane które powinny być zapisane na kartę SD (program wyświetla i zapisuje wartości z trzech wejść analogowych do których można podłączyć np. czujnik LM35). W przypadku błędów inicjalizacji karty SD lub błędów zapisu stosowne informacje będą również wyświetlone.
6) Po pewnym czasie (kilku minutach) odłącz płytkę od zasilania, wysuń kartę ze slotu i włóż do czytnika w swoim komputerze PC. Odczytaj zawartość pliku z danymi i sprawdź, czy są one poprawne.

## 5.7 Używanie modułu radiowego

Do tego przykładu potrzebne będą dwie płytki CanSat Kit – jedna będzie pełniła rolę nadajnika (CanSat), a druga odbiornika (stacja naziemna).

## 5.7.1 Konfiguracja nadajnika

1) Otwórz | przykładowy | program | „File | → | Examples | → | CanSatKit | →
RadioTransmitHelloCanSat” i wgraj go na płytkę.
2) Otwórz monitor portu szeregowego, zaobserwuj pojawiające się komunikaty – porównaj z poniższymi:


3) Zaobserwuj miganie diody D13 – sygnalizuje to poprawną pracę nadajnika.

## 5.7.2 Konfiguracja odbiornika

Następnie należy uruchomić odbiornik radiowy na drugiej płytce.

1) Podłącz drugą płytkę do komputera.
2) Wybierz port COM odpowiadający drugiej płytce.
3) Otwórz przykładowy program „File → Examples → CanSatKit → RadioReceiver” i wgraj go na płytkę.
4) Otwórz monitor portu szeregowego, zaobserwuj pojawiające się komunikaty – oznaczają one odebrane pakiety:


5) Parametr RSSI (Receiver Signal Strength Indicator) wskazuje siłę sygnału w odbiorniku. Zaobserwuj jak zbliżanie i oddalanie płytek wpływa na wartość RSSI.

## 5.8 Podłączenie anten

🛈
Krótkodystansowa komunikacja np. podczas testów oprogramowania może odbywać się bez anten.

Polecaną anteną do płytki umieszczonej w minisatelicie CanSat jest ćwierćfalowa antena monopolowa wykonana z giętkiego przewodu typu linka/drut o długości około 14 cm. Taka antena może być przylutowana bezpośrednio do środkowego pola lutowniczego oznaczonego CN1/ANT:

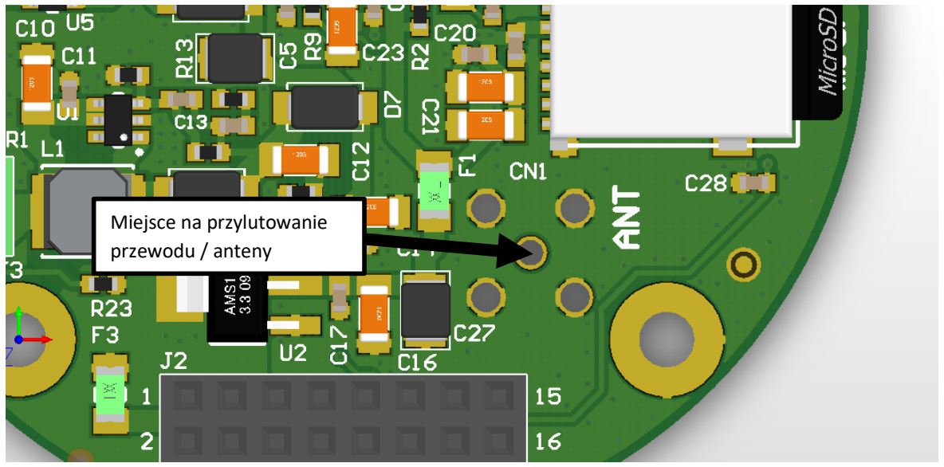
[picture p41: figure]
Miejsce na przylutowanie przewodu / anteny

Przewód należy zabezpieczyć przez ułamaniem w miejscu lutowania – należy zrobić tzw. „stress relief” (https://i.stack.imgur.com/vnF6U.jpg) za pomocą np. kleju epoksydowego lub na gorąco.

Do płytki stacji naziemnej przewidziane jest złącze SMA, które należy wlutować w miejsce CN1/ANT w następujący sposób:

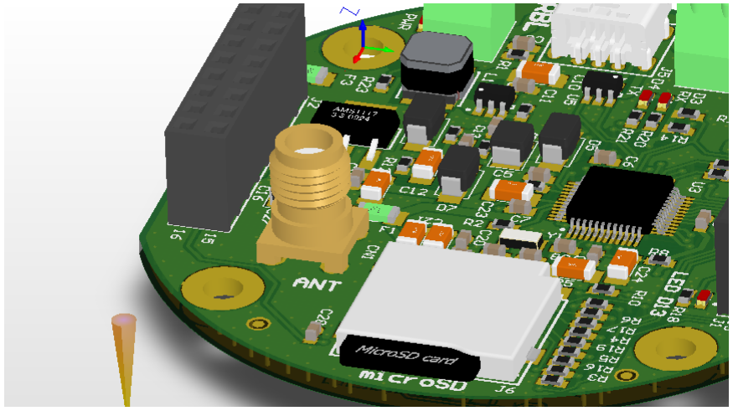
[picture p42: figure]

Do takiego złącza można przyłączyć większą antenę np. typu Yagi-Uda za pomocą kabla koncentrycznego 50 Ω.

## 6 Zestaw analogiczny

Zestaw CanSat Kit można odtworzyć przy użyciu ogólnodostępnych komponentów i modułów elektronicznych. Prototypowanie, eksperymenty i testy, które mogą spowodować przypadkowe uszkodzenie zestawu CanSat Kit poleca się przeprowadzać na zestawie analogicznym.

## 6.1 Lista elementów zestawu analogicznego

- Arduino M0 (lub odpowiednik np. Wemos SAMD21 M0) x 2
- Moduł radiowy SX1278 x 2
- Moduł czytnika kart SD x 2
- Moduł czujnika ciśnienia BMP280 x 1
- Czujnik LM35 x 1
- Płytka stykowa x 2
- Kable połączeniowe do płytki stykowej i modułów

## 6.2 Podłączenie modułów

Moduł radiowy należy podłączyć do Arduino M0 zgodnie z rozdziałem 4.1.7 Moduł radiowy, natomiast czytnik kart micro SD zgodnie z rozdziałem 4.1.6 Czytnik kart microSD. W obu przypadkach należy pamiętać o podłączeniu zasilania zgodnie z wymaganiami zakupionych modułów. Czujniki LM35 i BMP280 należy podłączyć w identyczny sposób jak do płytki głównej CanSat Kit.

## 6.3 Różnice i ograniczenia

Zestaw analogiczny dostarcza takie same poziomy napięć jak zestaw CanSat Kit (3.3 V, 5 V), jednakże wydajność prądowa poszczególnych linii zasilania może być inna, w zależności od zakupionej wersji Arduino M0 lub jego odpowiednika.

Zestaw analogiczny nie może być zasilany z baterii/akumulatorów o takim samym napięciu jak zestaw CanSat Kit.

Po pomyślnych testach na zestawie analogicznym należy przeprowadzić testy na zestawie CanSat Kit!

Testy zasięgu radiowego powinny być prowadzone na zestawie CanSat Kit ze względu na duży wpływ toru radiowego i anten na osiągi.

## 7 Bezpieczeństwo i zasady prawidłowego użytkowania

1) Zestaw przeznaczony jest do celów edukacyjnych, badawczych i rozwojowych.
2) Użycie zestawu na zewnątrz wymaga zastosowania obudów chroniących przed wilgocią,

bezpośrednim kontaktem z wodą, zanieczyszczeniami i pyłem.

3) Zestaw powinien być zasilany zgodnie z instrukcjami zawartymi w niniejszym dokumencie.

Nieprawidłowe podłączenie zestawu może doprowadzić do jego uszkodzenia i komponentów

podłączonych do zestawu, silnego nagrzania elementów, wzniecenia otwartego ognia, a nawet

eksplozji akumulatorów (jeśli były podłączone).

4) Zewnętrzne urządzenia elektroniczne powinny być podłączone do zestawu przez dedykowane

do tego złącza wymienione w rozdziale 4.1.2 Mapa złącz, gniazd i diod LED. Podłączanie,

lutowanie czy wprowadzanie innych modyfikacji do zestawu skutkuje utratą gwarancji i może

doprowadzić do uszkodzenia zestawu. Należy przestrzegać ograniczeń odnośnie użytkowania

wyprowadzeń zestawu i podłączania urządzeń zewnętrznych, które są wymienione w niniejszej

instrukcji.

5) Zestaw jest czuły na wyładowania elektrostatyczne ESD, które mogą doprowadzić do

uszkodzenia części lub całości urządzenia. Zaleca się stosować procedury zmniejszające ryzyko

powstawania wyładowań elektrostatycznych (maty, opaski uziemiające itp.).

6) Zestaw nie powinien być użytkowany w przypadku stwierdzenia widocznego uszkodzenia

jakiejkolwiek jego części do czasu zweryfikowania wpływu zaistniałego uszkodzenia lub

naprawienia usterki.

7) W przypadku stwierdzenia nadmiernego nagrzewania się elementów zestawu, podejrzanego

zapachu, pojawienia się dymu lub ognia należy natychmiast odłączyć cały zestaw od wszelkich

źródeł zasilania.

8) Elementy zestawu należy czyścić za pomocą suchej lub nasączonej alkoholem izopropylowym

antystatycznej ściereczki. Wyjątek stanowi czujnik ciśnienia BMP280, który może być

czyszczony tylko ściereczką suchą.

9) Zużyte elementy zestawu powinny zostać zutylizowane zgodnie z obowiązującym prawem,

w szczególności nie mogą być wyrzucane wraz z odpadami ogólnymi.

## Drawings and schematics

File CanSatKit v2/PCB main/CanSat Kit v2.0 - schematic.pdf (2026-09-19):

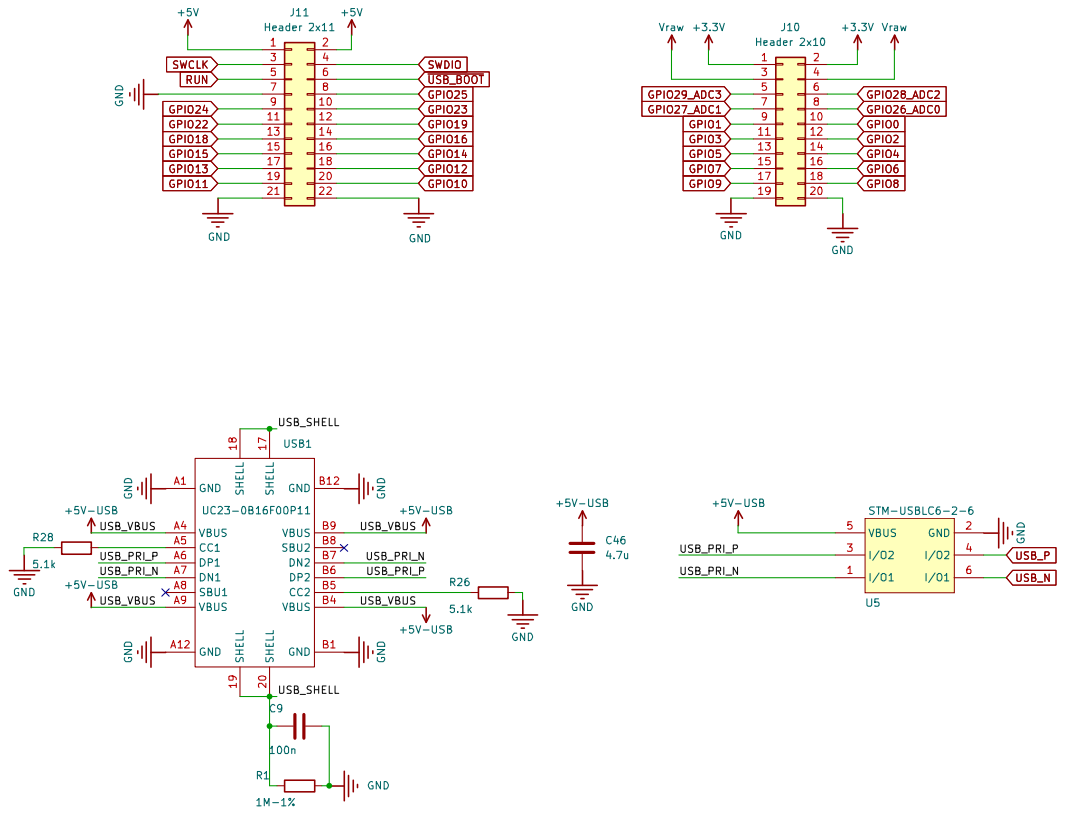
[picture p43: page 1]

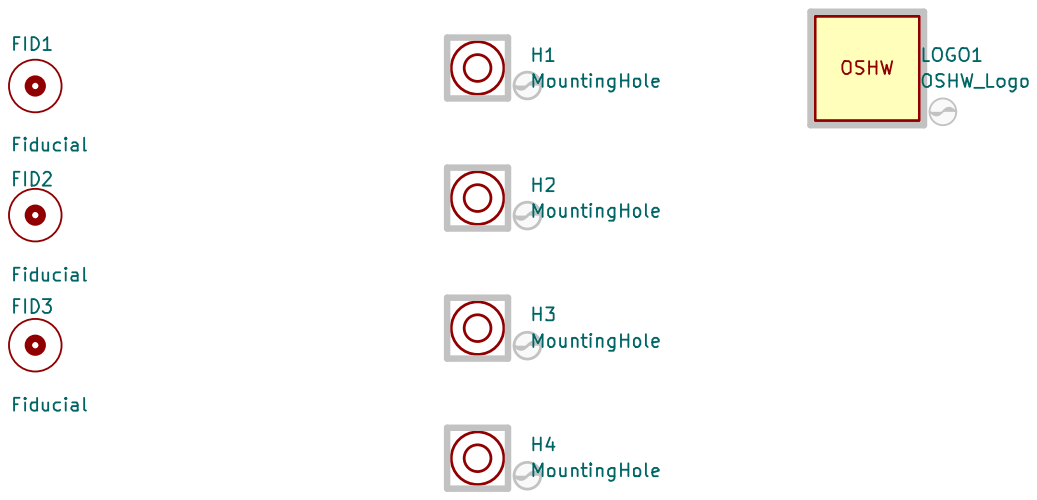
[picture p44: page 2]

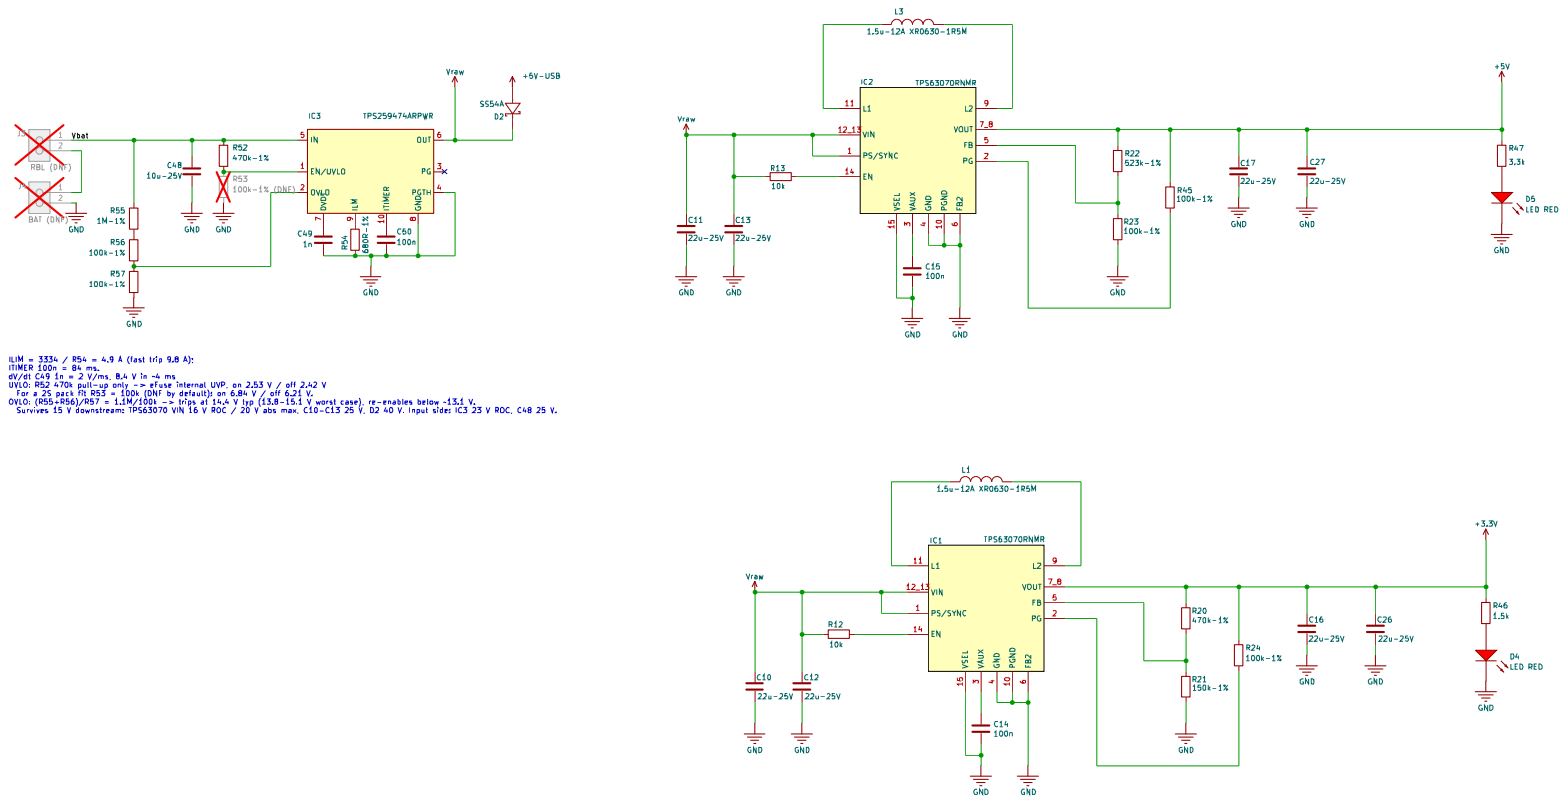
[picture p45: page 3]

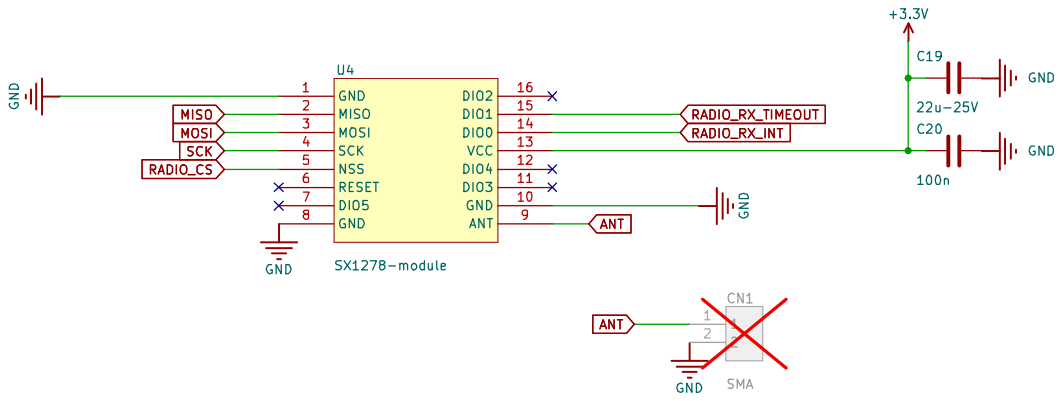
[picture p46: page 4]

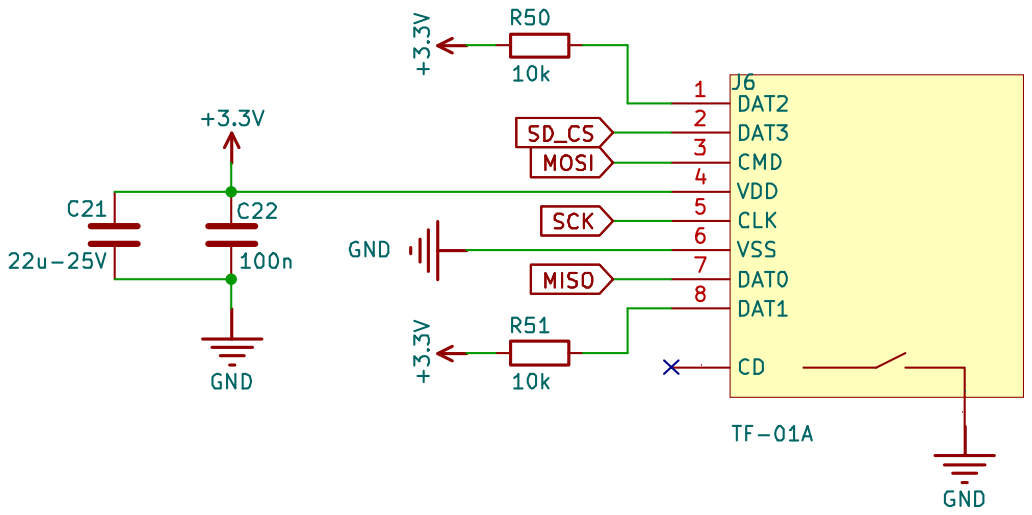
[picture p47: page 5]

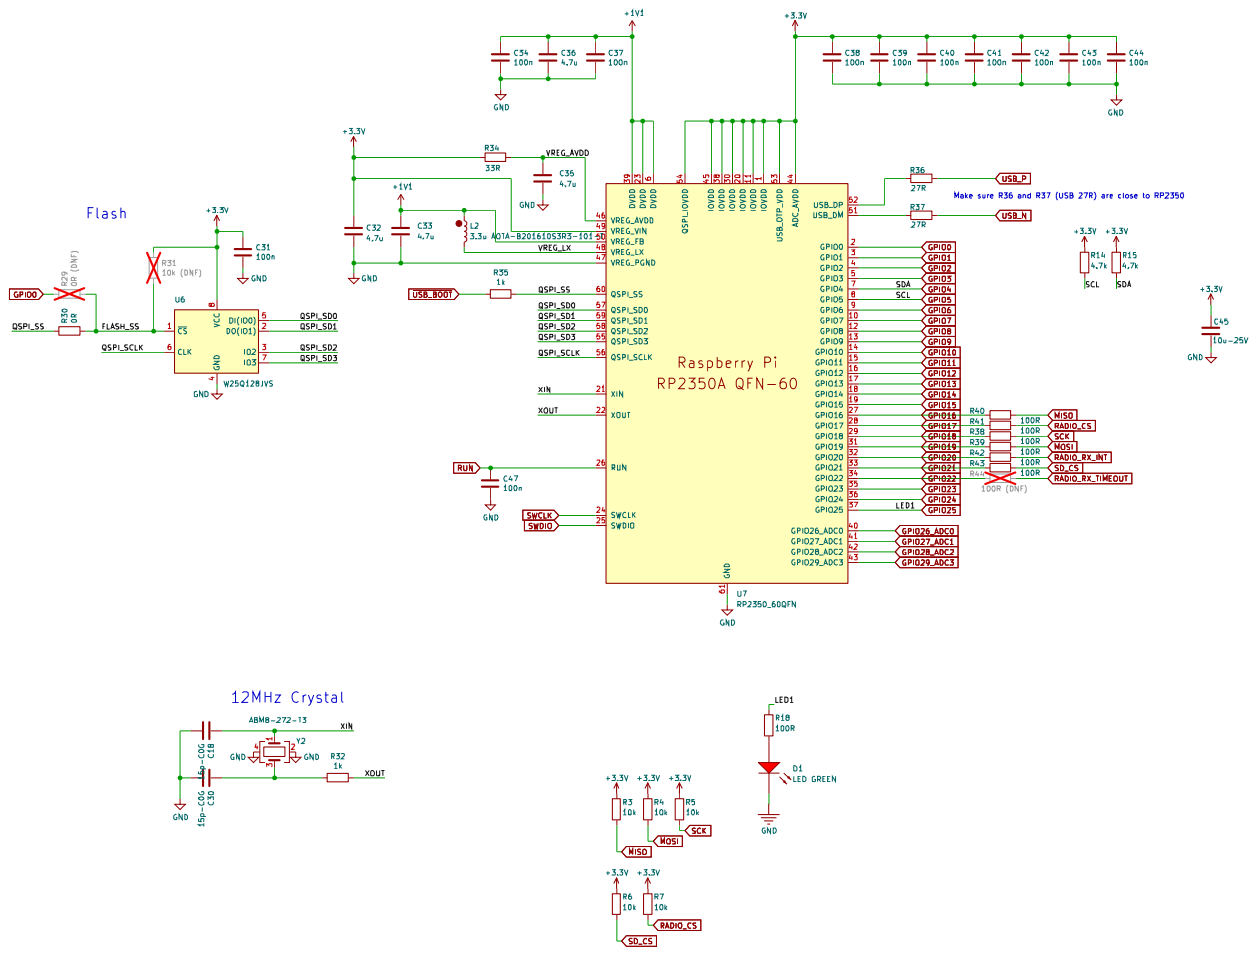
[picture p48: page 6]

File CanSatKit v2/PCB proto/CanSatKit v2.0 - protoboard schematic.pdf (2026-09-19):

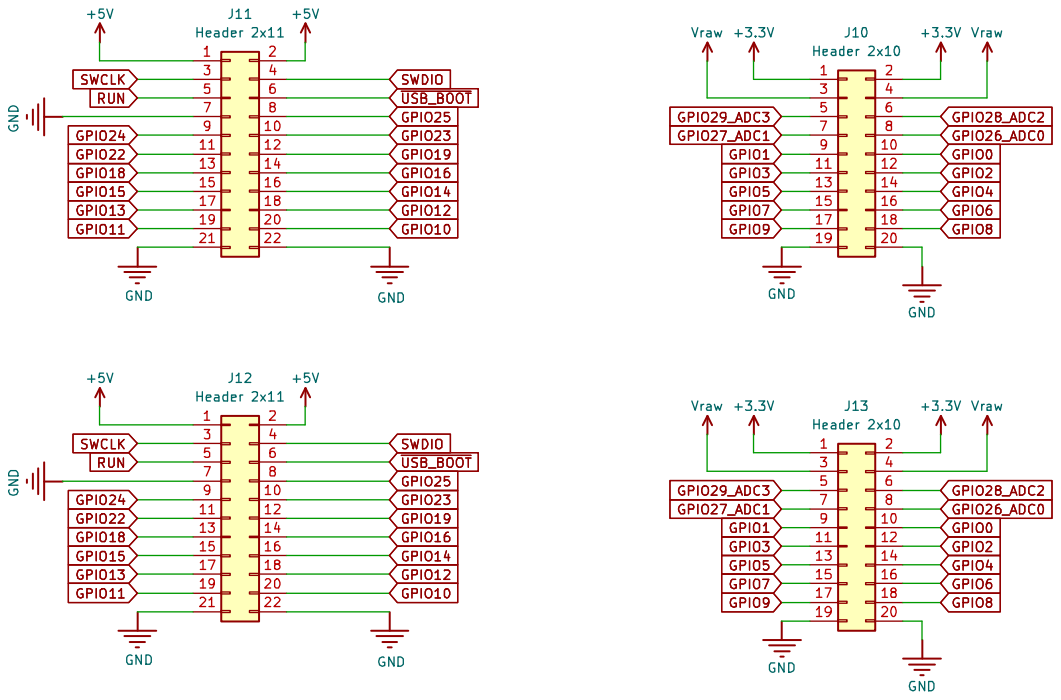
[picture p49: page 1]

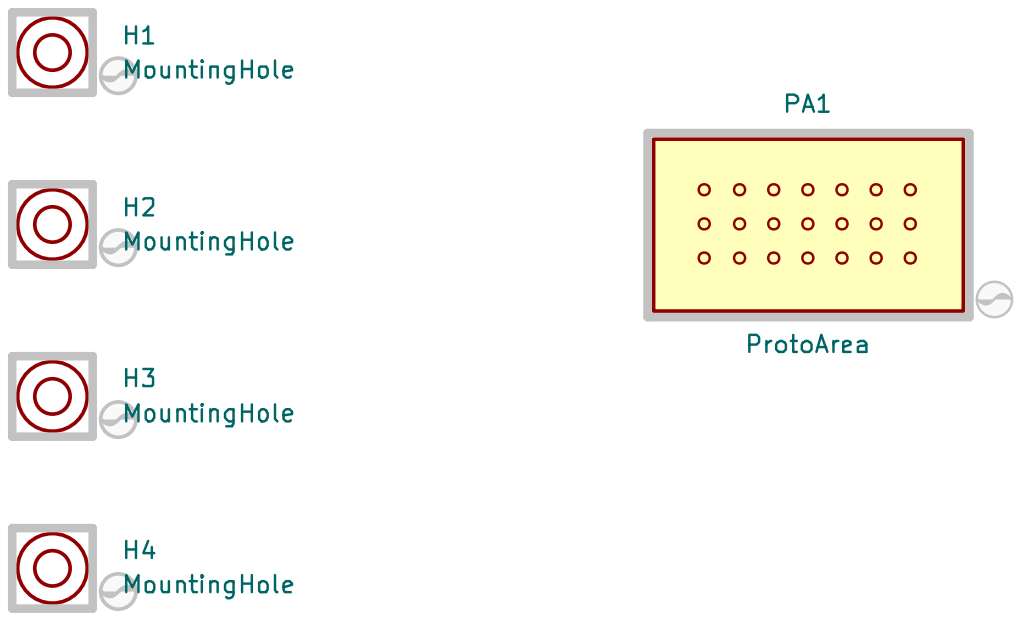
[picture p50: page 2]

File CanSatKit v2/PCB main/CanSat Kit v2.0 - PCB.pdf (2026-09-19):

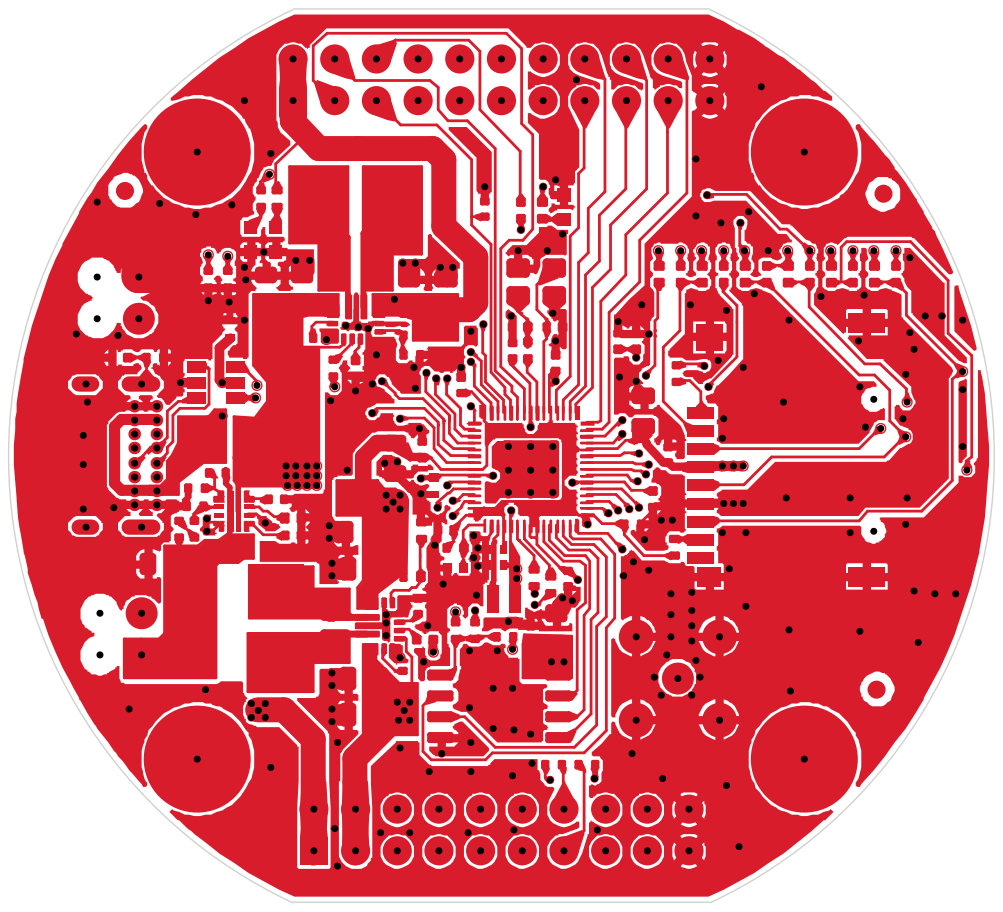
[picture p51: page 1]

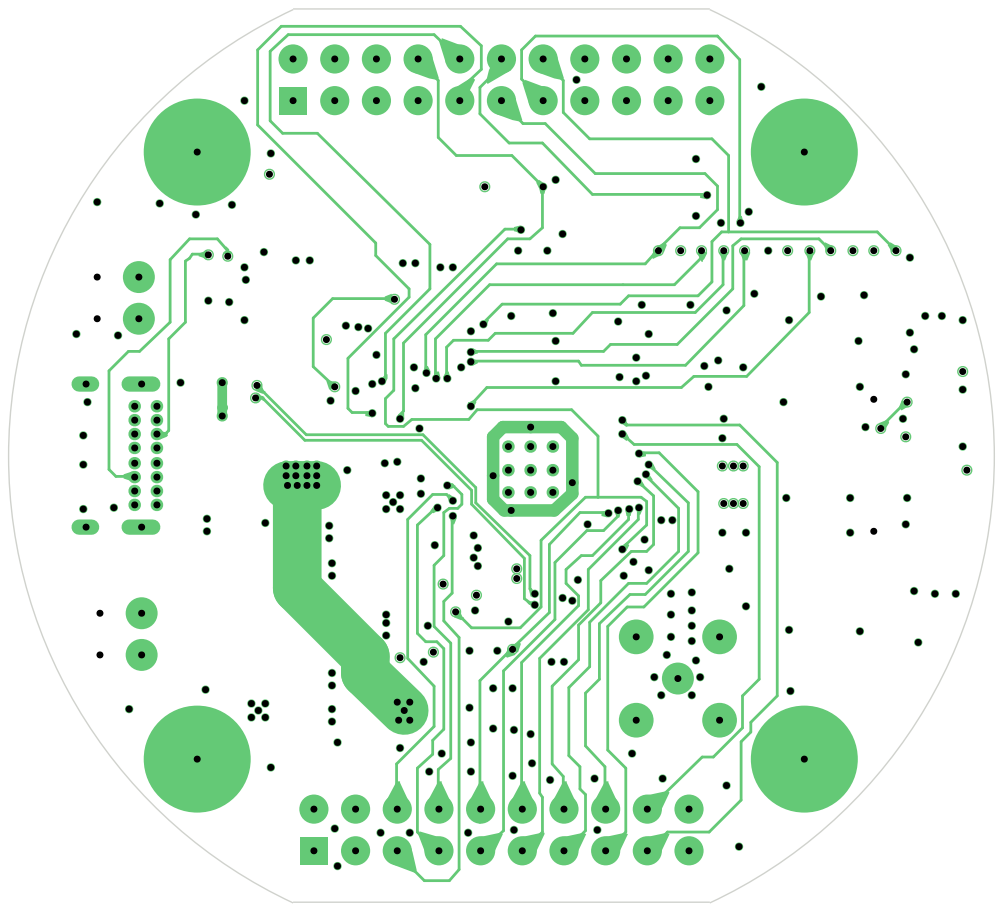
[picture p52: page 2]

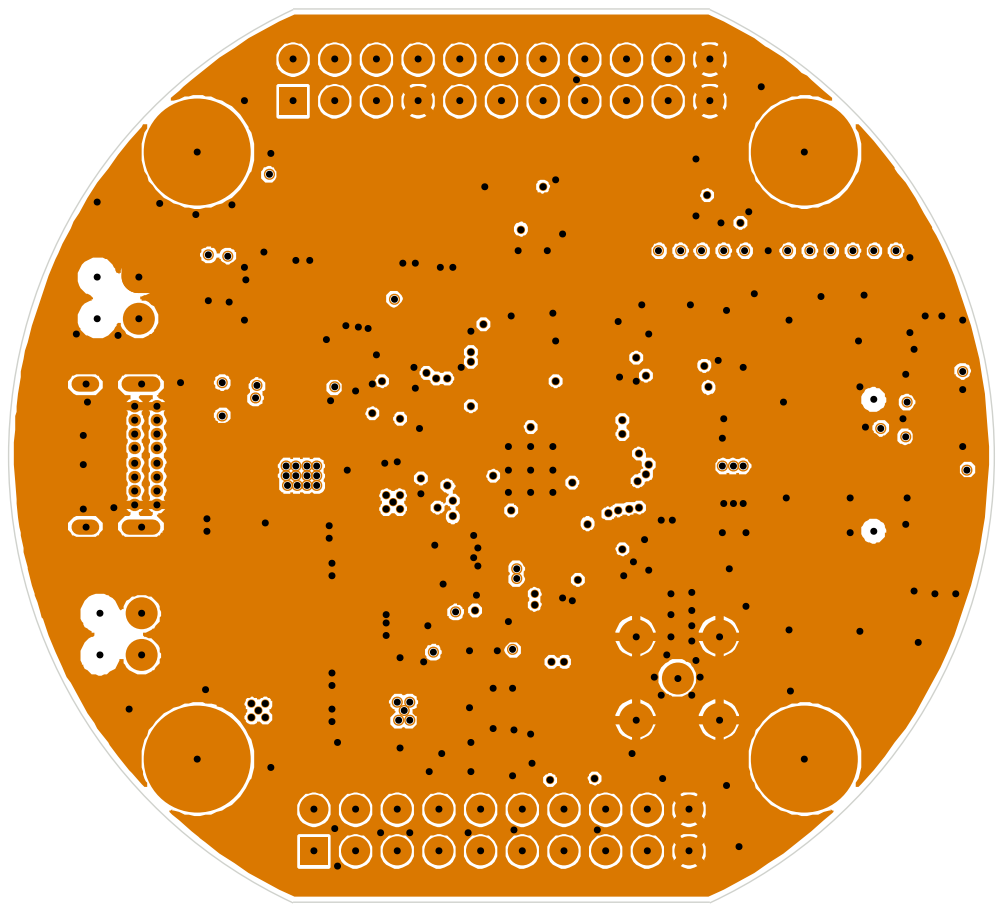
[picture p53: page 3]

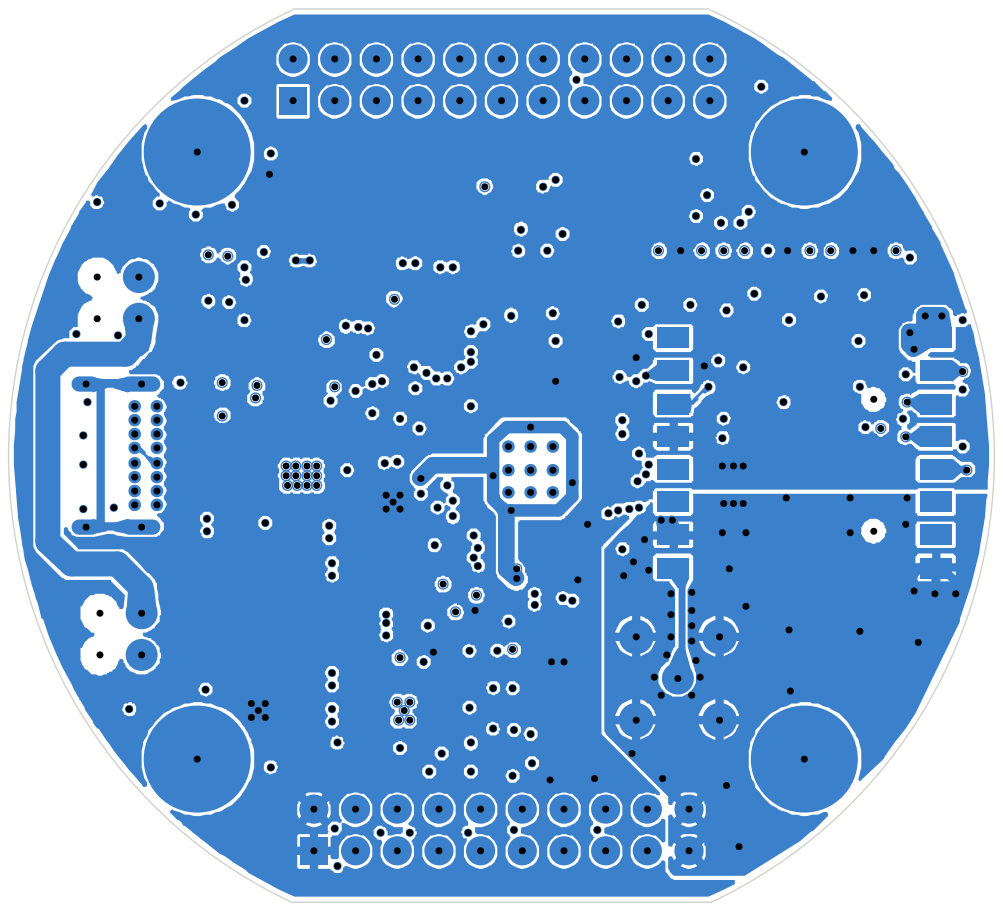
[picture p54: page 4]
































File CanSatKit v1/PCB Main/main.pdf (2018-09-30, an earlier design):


Mic rocon trolle r u n it Ti t l e | ****

Size: A | Number : | Revi s ion:
Date: Ti me: | | Sheet * of


Connectors Title | * * * * *

A4 Size: | * Number: | * Revision:
9/30/2018 Time: 5:40:14 PM | | Sheet of *

VSS 1; 2 ams; F2ECE E; xcel Cel; ECE E; F3ECE E

Power Supply Unit *

A4 Size: | N umber: | * Rev i s i o n :

/ / T ime: 4 PM | | Sheet o f

dio transceiver *

A4 Size: | N umber: | * Rev i s i o n :

/ / T ime: 4 PM | | Sheet o f


Micro SD Card*

A4 Size: | N umber: | * Rev i s i o n :

/ / T ime: 4 PM | | Sheet o f






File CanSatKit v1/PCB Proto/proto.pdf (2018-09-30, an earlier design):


Sheet o; SCL D5; SCK D13 D8 D6; MOSI D7 D9; PIJ1014 NLA0 PIJ1013 NLA1; PIJ1016 NLA2 PIJ1015 NLA3; PIJ1018 NLA4 PIJ1017 NLA5; PIJ1019 NLAREFA; PIJ108 NLD0 PIJ107 NLD1; PIJ1010 NLD2 PIJ109 NLD3; PIJ1012 NLD4 PIJ1011 NLD5; PIJ207 NLD6; PIJ208 NLD7; PIJ209 NLD8; PIJ2010 NLD9; PIJ2011 NLD13; PIJ2012 NLMISO; PIJ2014 NLMOSI; PIJ203 NLnRESET; PIJ2013 NLSCK; PIJ103 NLSCL; PIJ104 NLSDA; PIJ205 NLSERIAL50RXD; PIJ206 NLSERIAL50TXD; PIJ105 NLSWCLK; PIJ106 NLSWDIO


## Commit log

2018-09-30 Add PCB documentation
    [main-simple.step, proto.step]
2026-09-19 Add documentation v2
    [CansatKit v2.0 - protoboard simplified.step, CansatKit v2.0 - protoboard.step, CansatKit v2.0 - simplified.step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]
